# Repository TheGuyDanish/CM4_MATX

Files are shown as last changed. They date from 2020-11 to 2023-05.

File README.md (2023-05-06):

# CM4 MATX

## This project has been archived.

Due to a few different reasons, I have decided to archive this project. There's a few different reasons, but mainly that I don't think the CM4 is an appropriate platform for this kind of board. The CPU doesn't really have enough power to utilize the kind of IO that this board would provide it with, combined with the different limitations of using PCI-e switches. This, combined with the fact that I don't have as much time as I'd like to spend on this project, I've decided to leave it be for now.

I'm not aware at the time of writing of any similar projects, but I'll be leaving this one up for folks to take resources and inspiration from.

The original readme is below for archival purposes. So long, thanks for all the fish, and may you have the best of luck in your projects!

/TheGuyDanish

<hr />

Welcome! CM4 MATX is a project aiming to create an open source, micro-ATX standard-compliant motherboard for the Raspberry Pi Compute Module 4.

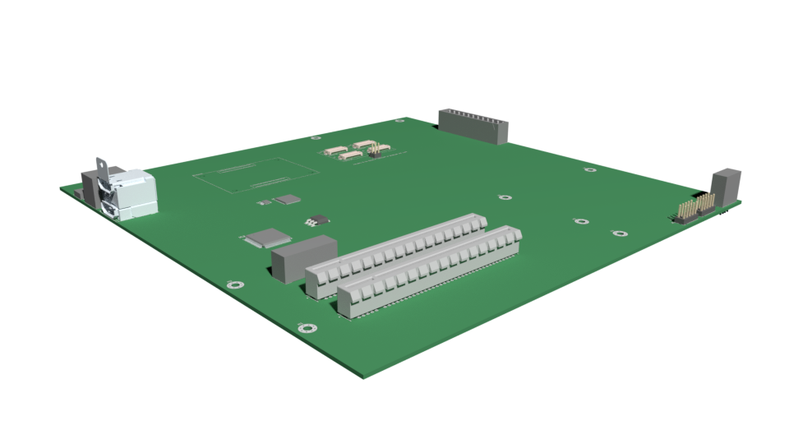
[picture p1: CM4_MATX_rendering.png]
3D rendering of the PCB (design not final)


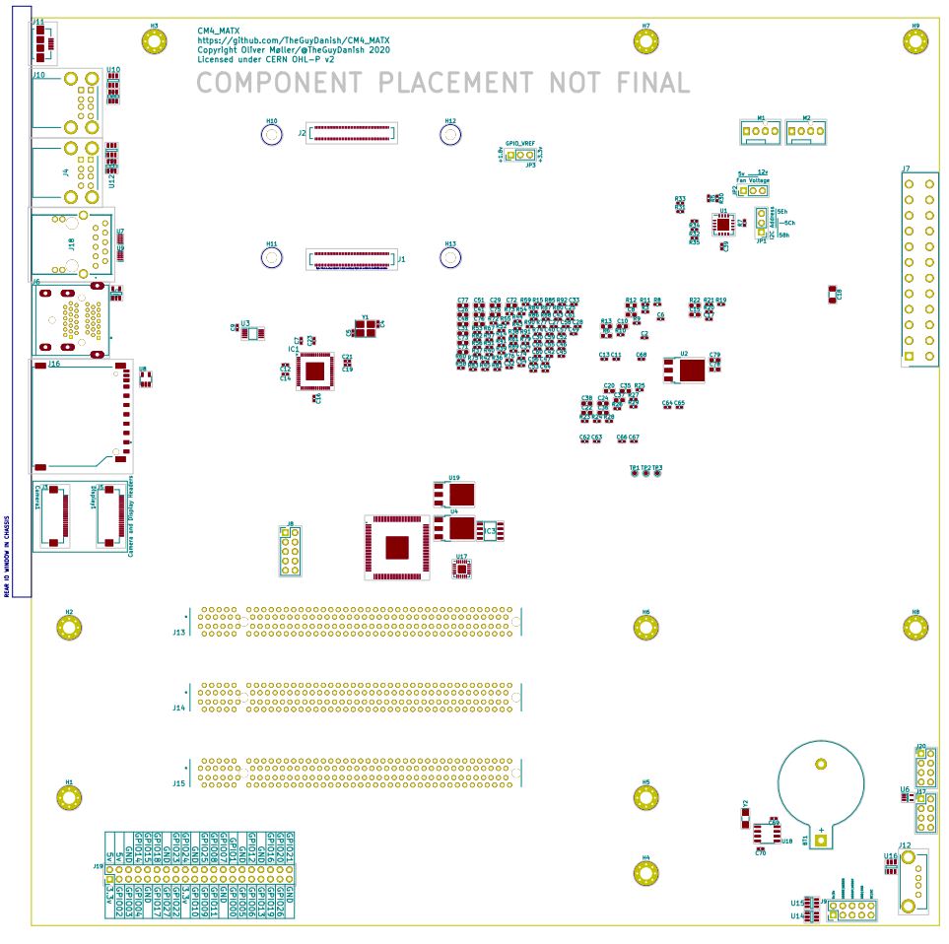
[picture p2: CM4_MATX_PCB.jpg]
PCB layout - click to view current PDF
<p align="center"></p>

The intent behind this is to provide a motherboard that can be installed in a regular case, as well as provide more, or easier access to, potential IO, as well as using a standard 24-pin ATX power supply. This project uses much of the CM4 IO board as its reference design, with new features added onto the board.

The current design goals are as follows:
* Use a standard mATX form factor (244*244mm) and mounting holes
* Provide dual rear-panel USB ports via USB2514B/M2 USB Hub
* Provide an internal USB expansion header for front-panel USB ports
* Provide a standard gigabit Ethernet interface for the rear panel
* Provide stacked dual HDMI outputs on the rear panel
* Provide stacked dual HDMI inputs on the rear panel, with the aid of the Toshiba TC358743 CSI2-to-HDMI bridge IC
* Where reasonably possible, expose the dual DSI headers
* Provide rear-panel acess to other RPI staples, such as SD card and 40-pin GPIO headers
* Via the PI7C9X2G404SL PCI-e switch IC, provide three lanes of PCI-e Gen 2.0 to host multiple expansion cards. These will be x16 slots, wired x1 electrically, to reduce the need for adapters
* Via the PI3PCIE2215 PCI-e mux IC, offer the user the choice between a physical PCI-e slot, or an NVMe slot using one of the downstream PCI-e lanes from the above switch.

# Help Wanted

Update: We have reached a state where we feel comfortable beginning to route the different features of the board. If you have experience with routing PCBs, you are very welcome to download the Kicad files and have a look for yourself. If you have any questions, feel free to join us on Discord if you have any questions and would like to reach out to me directly!

I (TheGuyDanish) am not an experienced board designer, nor a whiz at electronic schematics. That's why I am posting this to Github. I'd love for other hobbyists to join this project. Not just to correct my inevitable mistakes, but also to suggest new features that would make this board even better.

For technical specifics, the KiCad project was made in version 5.1.8 stable. All components not found in the standard KiCad library are included in the CM4_MATX.pretty folder (PCB footprints) and CM4_MATX.lib (schematic symbols) file.

Please see CONTRIBUTING.md for more information!

If you have the technical skills to improve this schematic, I do implore you to make a copy of the repository, make your changes and submit them in a pull request.

If you have ideas you would like to add to the design goals, please submit them in an issue so they can be discussed.

Lastly, huge thanks to volkertb, UnKnoWn-Consortium, mo-g and geerlingguy for the discussion of this in https://github.com/geerlingguy/raspberry-pi-pcie-devices/issues/19 that spawned this effort.

# License

NOTE: Some models, schematics, and/or footprints, are provided by individual manufacturers. As such, all terms and conditions for use, as well as licensing, falls to these original manufacturers. For more information, please inquire with the original component manufacturer or raise an issue here.

Copyright Oliver Møller/[@TheGuyDanish](https://github.com/TheGuyDanish) 2020.

This source describes Open Hardware and is licensed under the CERN-OHL-P v2

You may redistribute and modify this documentation and make products
using it under the terms of the CERN-OHL-P v2 (https:/cern.ch/cern-ohl).
This documentation is distributed WITHOUT ANY EXPRESS OR IMPLIED
WARRANTY, INCLUDING OF MERCHANTABILITY, SATISFACTORY QUALITY
AND FITNESS FOR A PARTICULAR PURPOSE. Please see the CERN-OHL-P v2
for applicable conditions

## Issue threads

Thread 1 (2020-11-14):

Pi-Standard 40-pin connector should be discarded

mo-g, 2020-11-14:
So in order to provide the high res 4-lane CSI, the i2c pins are needed. The i2s interface is also needed for sound capture from HDMI. By counterpoint, the CM4 exposes ADC interfaces on the SOM connector that are not exposed through the standard pi 40 pin. It also doesn't expose the 12V rail we have access to through the ATX PSU.

Additionally, the 40-pin IDC connector is not "external grade" hardware.

Since many hats already won't work with the hardware above missing, I propose making a "different" 40-pin connector exposed internally which is not pin-compatible with the standard Pi header, then breaking that out onto the I/O shield with a 37 pin D-Sub connector on a ribbon cable. - Inspired by the Be Inc Geekport.

TheGuyDanish, 2020-11-14:
A good point. This is easy to change this early (because I haven't drawn the 40-pin header into the schematics yet). Next prominent question is what other pins we might want to cut away if we are to put the GPIO on an alternate connector? I'm still leaning more towards exposing the GPIO as an IDC header on the rear-panel to keep it user friendly to anyone who wants to experiment with the GPIO. Rather than someone having to break out whatever connector we'd use instead back into regular 2.54mm pins.

mo-g, 2020-11-14:
By my count, 8 of the pins on the Pi header are Grounds. We could *probably* tie some of them together (says the non-electrical engineer)

Exposing it internally but offering a plug-in breakout gives people flexibility. They can use it entirely internally, for something like a panel-mount LCD or Fan control, or they can expose it through a safe and protected connector which has things like a screwlock to hold it in place, *or* they can just run a good old fashioned IDE cable out of any crack in the case to run it externally without having to solder up a DB37.

If we expose it only externally as IDC - they need to run a ribbon back into the case to do internal projects (fragile and inelegant) - and if using it on their desk, they risk knocking the cable out - potentially damaging their project or piatx logic, but almost certainly damaging the IDC header itself. I do NOT miss bending pins in IDE sockets trying to get a tight fitting drive cable out.

volkertb, 2020-11-14:
You two are obviously more well-versed in this than I am, but what about the way how the Raspberry Pi 400 has exposed these pins on the back? Would it make any sense for us to maintain some compatibility with that?

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

mo-g, 2020-11-14:
That's basically what @TheGuyDanish is proposing. The two reasons I'm arguing against that approach:

1. We can't be pin compatible anyway, and doings something that "looks" like a Pi standard is likely to lead to people breaking things by plugging "Pi standard" things into it.

2. A fragile connector like that is fine on the Pi 400 because:

- It's a cheap, £70 computer. The board we're designing would likely be more expensive.
- It's designed to be used on your desk or table right in front of you. An ATX case isn't - this connector is going to be awkwardly hidden away from you, and ribbon cables are a poor choice for that scenario - which is why desktop PC's always use D-sub connectors for UART, GPIO and A2D - because they are rugged connectors.
- And finally, as I said above, doing it this way prevents you from building something that sits internal to the computer - like an LCD or an ISA bus or a fan controller. That's fine on the Pi 400 because there's no free space inside it anyway and you can't easily open it to find out. Not true of an ATX case.

TheGuyDanish, 2020-11-14:
> (says the non-electrical engineer)

That's still more engineer than I am.

Entertain this thought for a moment. With the microATX standard, we can expect any case this board is put into to have room for four expansion cards. Given the PI7C switch IC we're using can only support three lanes, If we expose the IDC header (or whatever connector we end up using) at the bottom of the board, where the last PCI-e slot would be. It could be possible for a user to (somewhat elegantly, with a custom PCI-e bracket with the right cutout) expose the IDC header, should they really want to. Otherwise, it would be kept internal and can either be accessed or ignored, depending on the user preference.

mo-g, 2020-11-14:
That's basically the same concept as mine, except using a backplane slot rather than a D-Sub. I'm fine with that - reminds me of the way old Winmodems connected to boards in the late 90's, and allows people to export it as D-Sub, IDC, whatever they want - or mount it as an internal card, kind of like a custom "PiBus". I like that approach. Will need careful positioning to allow a simple PC case to have a standard ATX case bracket on and still align correctly with the IDC connector.

volkertb, 2020-11-14:
I like this Winmodem/"PiBus" approach too, the more I think about it. Let the community develop all sorts of interesting cards around this new form factor. Legacy I/O (serial, parallel), sound cards, cards that would expose the pins on the backplate in the form of the aforementioned Geekport or the same port as on the Raspberry Pi 400 if they want, etc.

Are there any kinds of I/O that we would still want to integrate on the board, and which would take up any of the GPIO pins? I believe one of you mentioned an on-board RTC, for instance?

TheGuyDanish, 2020-11-14:
On-board RTC is present in the CM4IO board and could easily be lifted if we want to integrate it.
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

mo-g, 2020-11-14:
I'd definitely be in favour of RTC, since it is pretty mandatory for any kind of server needing certificates. I've also already mentioned using i2c and i2s so that which can turn the pair of CSI2 ports into something useful. And I've mentioned a few times I want to ADD the A2D pins to the header, which are missing on the standard pi header. That said, I've just stuck a question up on the Pi forum because I'm a little confused about how i2c plays out with the CSI, etc.

I want GLOBAL_EN, RUN_PG (reset), LED_PWR, LED_nACT (HDD) on the fpanel connector but I don't think any are on the 40-pin header to start with.

TheGuyDanish, 2020-11-15:
@mo-g I've done some research this evening, and I actually think we can present i2c pins on the GPIO header without drawbacks. While the TC358743XBG internal registers _can_ be modified over i2c, it doesn't seem to be a hard requirement. If you look to some of the boards that demo it, such as the [Auvidea B101](https://auvidea.eu/images/auvidea/products/bridge/B101/B101_test_setup_RPi_600x350.jpg), they aren't connected to the GPIO pins at all, meaning the chip surely doesn't require the i2c connection.

In addition, after some more reading up, connecting two of these chips (which would be necessary to facilitate two HDMI inputs) to i2c would cause another conflict, in that they'd likely conflict on their i2c addresses. Newer versions of this IC have a specific selector to allow you to chose either a master or a slave i2c address to prevent these collisions, but the one we're looking at for this doesn't.

In summary: **_i2c for the people!_**
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
TheGuyDanish, 2020-12-12:
As I've had no comments on this, and the 40-pin header is now exposed on the port (location pending final placement), I'll go ahead and close this issue for now. Any outstanding comments are still welcome.

funkyguy4000, 2020-12-18:
Are we sure that we want the 40-pin header at the bottom of the board? It looks like there might be some overhang which might not allow the motherboard to fit in a standard Micro-ATX case if the user wants to use the 40-pin as is. It seems like we might have better luck having the spot where the 40-pin header is be some sort of other card edge connector, maybe a little offset a little closer to the bottom of the board, and then there would just be an adapter card that turned it into a standard 40-pin. That could then put the connector opposite the other side of the pi HAT so the traditional output side of the HAT is out the back like a standard PCIe card.

TheGuyDanish, 2020-12-18:
I'm anticipating that we may have more spare room on the bottom of the board, especially behind where the 40-pin header is located now.

We could move the 40-pin header further back, perhaps behind where the PCI-e slots are now, then let users decide if they want to put a HAT on it, or use something like a 40-pin IDC header to bring it somewhere else.

One of the ideas I think we originally discussed for this was something like a simple PCI-e bracket/card to expose the 40-pin header externally, so it would be similar to the Pi 400 in appearance. That way, people can use it, both inside the case, and on the outside, if desired. Though the placement of the header itself doesn't really matter in that context.

As ever, I'm happy to hear other options, though. I really want to avoid adding another layer of complexity to it in the form of new connectors. If any new connector is to be added, I would like for it to be one that is fairly common, that people wouldn't struggle to track down cables and mating parts for.

mo-g, 2020-12-21:
I previously had the same thought, @funkyguy4000 - but - if the 40-pin connector is aligned properly, a card with a female header block soldered to it and a standard PCIe bracket screwed on - would sit on the header no differently to using a card-edge.

If someone wants to use the hat connector, they could use a bigger case - or more likely, use a "vertical riser" that lets any ports on the hat stick out of the back of the case. That could also add a geekport connector, or a 40 pin HAT-on-the-Back, or something completely custom.

@TheGuyDanish
> If anyone has requests for other pins, please post a comment in here with their names and locations and I'll look into including them on a separate header near to the GPIO header.

`IP0, IP1. nRPI_BOOT, EEPROM_nWP` would be the other pins I'd want exposed on that connector.

If you went for a 48 pin header, then you could have IP0/IP1 as a row, pair each of BOOT/nWP with a ground to allow them to be pulled low, then have a pinless-row to keep them physically separate from the rest of the 40 pin?

TheGuyDanish, 2020-12-21:
@mo-g IP0 and IP1 will need to be exposed somewhere, for sure.

nRPIBOOT and EEPROM_nWP are already exposed on J20, the 2x4 pin header on the bottom right hand side of the board.

funkyguy4000, 2020-12-21:
Just throwing an idea out here, since the nRPIBOOT and EEPROM_nWP are critical to using the CM4, relative to the board purchased, would it be possible to wire those to toggle switches somewhere? Maybe the IO Shield, maybe somewhere internal? It'd be a simple feature to implement and a large portion of the users will need to do this function already.

mo-g, 2020-12-22:
Simplest answer would just be to have them on a header adjacant to a ground pin - that way they can be jumpered where they are, or put on a toggle with nothing more than a crimped plug and two lengths of wire. That gives a lot more flexibility as well, since you can run the wire to the back of the case, or to a front drive bay.

I don't see an I/O shield toggle being useful. For the effort of getting to it where my desktop is, I'm as well off to take the side panel off and change a header. I appreciate everyone's desk is different! I'd also be worried about accidentally switching it while moving the PC into place. Since you only need these for a firmware update (and most users of this aren't going to need to set nWP) or if you spectacularly hose your OS (BOOT) - I don't see them really needing easy external access.

Maybe an I/O shield DIP switch would work better, if you were to move them anywhere?

erkinalp, 2021-05-13:
With a +VCCs and a few GNDs merged amongst each other, a 29-pin HDMI dual link connector could be reused.

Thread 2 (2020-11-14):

Expose both a USB pin header and a USB-A socket internally

mo-g, 2020-11-14:
This is something cribbed straight out of Supermicro's playbook, but I think we should absolutely borrow it.

The design as current exposes two USB 2.0 headers. I propose we only expose one header and expose the other as a USB type A socket.

The reason is, there are many USB devices that would make sense to use internally in a Pi based PC which are only available with A connectors and not header blocks:

1. USB-SATA adapters. Many people use these, as they connect a standard 2.5" ssd to a USB socket. With an internal USB port, one could be mounted in a normal drive cage and still used as a Pi's boot drive - handy, since NVMe boot support is not available.

2. USB flash drive. See above, except cheaper. A USB flash drive could hold the pi's bootloader only, for booting to NVMe. Allows easy use of NVMe with the Pi CM4 lite, potentially allowing the eMMC interface to be used for something more useful. (We're exposing that as a header block too, right?)

3. USB-Floppy disk drive interface. Something like this - https://www.ebay.co.uk/itm/264239344659 - Which allows an internal 3.5" drive to be mounted for retrogaming fun. But, it needs a USB-A, not a header.

As an alternative to this proposal, I'd also accept headers-only, as long as they were two physically separate four-pin headers, and not the common two-port 9-pin header block. That would allow something like a single port version of this to be made to allow both internal or external type connectors to be used in any combination: https://www.ebay.co.uk/itm/383805792699

mo-g, 2020-11-14:
Another alternative - use USB2517 instead of 2514 - two external ports, two complete 9 pin headers AND an internal USB-A.

TheGuyDanish, 2020-11-14:
There's definitely a potential for this and I was considering it when I was writing the design goals in the README. Most internal USB headers will expect the two-row header that normally is used for exposing USB 2 ports.

Using the 2517 could be an interesting fix, seeing as it should be a more or less drop-in replacement. I'll look into that.

TheGuyDanish, 2020-11-15:
I didn't mention this when I committed it yesterday, but https://github.com/TheGuyDanish/CM4_MATX/commit/08fd37ccbf002c83fe7bd2444757735594c0ec7e put a lot of my work on this into the repo. The USB2517 is placed, as are two 2.54mm expansion headers, the dual-stacked rear-panel USB connectors, and finally the vertical USB A header on the board itself. Totaling to all 7 ports. The file https://github.com/TheGuyDanish/CM4_MATX/blob/master/CM4_MATX_PCB.pdf shows where I expect to put these on the board, but would love to hear other thoughts.

There is still some work to go for USB, though. Namely:
* The VBUS rail doesn't exist yet. On the CM4IO board, the VBUS rail is made by putting 5V through an AP22653W6 power switch IC and using the output (with one decoupling capacitor per port) as VBUS.
* Power still needs to be attached to the USB2517 chip. I haven't done an exact count as of yet, but it's likely we'll need a few more decoupling capacitors for 3.3v rail on the power inputs on the USB2517 (IC1) and the FSUSB42MUX (U1).

I plan to look into this on Tuesday.

TheGuyDanish, 2020-11-24:
I believe this has large been completed. Anything that might remain now are overall steps, not anything specific to this issue, closing.

Closed 2020-11-24.

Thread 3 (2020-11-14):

Integrate an IEEE 1284 (Centronics) parallel port (not through a USB adapter)

volkertb, 2020-11-14:
Although it's considered a legacy interface, I'd very much like to see a parallel port on the backplate of this motherboard, for various (retro) tinkering purposes. One that supports bit-banging, a low-level feature that USB to parallel port adapters don't offer.

Perhaps you could implement this fairly easily by integrating the pi-parport HAT design at https://github.com/worlickwerx/pi-parport into your motherboard design?

I'm not sure if this would take up any pins that are already required to offer other types of integrated I/O that you plan to implement, but if not, this would be really nice to have.

mo-g, 2020-11-14:
This would use up a bunch of GPIO (actually, nearly all of it) - BUT, this is exactly the kind of thing that could be done via the 40-pin connector if we mount it next to a backplane slot. You could expose a 40-pin IDC externally, my "geekport" or use this schematic plus a MAX232 to give a parallel port and a serial port as an expansion card.

This could also be used, if you wanted to keep the 40-pin connector for something else, as well:
https://www.dell.com/en-uk/work/shop/dell-parallel-serial-port-pcie-card-full-height-for-mt/apd/540-bcgv/networking

mo-g, 2020-11-14:
As a side note, I want one of these GPIO to Parallel+Serial Port cards if this board ever gets built! I can think of a lot of uses for that! :D

volkertb, 2020-11-14:
Interesting alternative suggestion. I wouldn't want to sacrifice a precious PCIe slot for it, though. Indeed, having some kind of expansion card that plugs in to the GPIO pins and exposes such ports on the backplane would indeed be the way to go.

By the way, I was about to open a separate topic for requesting an integrated RS-232 DE-9 port as well, but I guess that's part of the same conversation. (Except that an RS-232 port wouldn't require a lot of GPIO pins and therefore could perhaps be integrated after all. What do you think?)

TheGuyDanish, 2020-11-14:
There wouldn't be any sacrifice. As mentioned in #1, the switch chip only supports three downstream PCI-e lanes. Seeing as the mATX spec covers four, we can put an IDC header with the GPIO where the fourth slot _would have_ been. This would allow anyone to potentially install HAT-based expansions into that fourth slot. It would require a custom bracket/cutout to expose it externally. But there wouldn't be any sacrifice involved.

volkertb, 2020-11-14:
Yeah, you both have convinced me that that's the way to go. In that case, I guess I can close this thread, right? Since exposing the GPIO pins through an IDC header would be more flexible than hard-wiring an integrated parallel port to some of the GPIO pins.

TheGuyDanish, 2020-11-14:
I think it's safe to close this, yeah. While the idea behind this is solid. It does definitely lean more towards being one part of a greater "expansion card"/PiBus project.

mo-g, 2020-11-14:
Side note - my original thought process for this (@TheGuyDanish) might have a different perspective) is to try and expose as many of the features as possible. The reason I want us to use the i2c and i2s for the HDMI in, is because doing so allows us to make use of the otherwise useless CSI ports.

Making a DB9 serial port would remove the UART fro being able to be used internally, but like the Parallel port - you need little more than a single IC (MAX232 TTL-RS232 converter) which is a long since common chip for DIY projects. :) You could easily fit them both on an expansion card - and even have a flying lead out to a DB15 game port on the card, too. For that full 1993 experience!

TheGuyDanish, 2020-11-15:
Closing this for now as it's pretty much agreed that this is out of scope for the board itself.

(And also so we can close our first issue. 🎉)

Closed 2020-11-15.

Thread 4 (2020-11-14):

Expose SDIO as a header next to the I/O shield, not as a soldered SD Card slot

mo-g, 2020-11-14:
According to the launch blog for the CM4, by holding the SOC in a reset state, the SDIO interface can be used to access the eMMC on a full fat CM4 for programming. Outside of that case it can also be used to add an eMMC module to a CM4 Lite, as an SD I/O interface in the classic sense for external hardware (GPS, modems, etc), or.. as an SD card socket.

The CM4 Carrier hard limits all of that to JUST being used as a storage medium by using a uSD socket. We should expose it as pins, and allow the end user to attach an eMMC module, a full size OR micro SD slot via a simple passive shim, or use the SDIO functionality for another device - OR, connect it to another computer to access the eMMC.

TheGuyDanish, 2020-11-22:
I do think this is a good idea, but part of me is wondering how we could do this in an elegant way. I think for Rev.1, having a soldered SD Card slot is acceptable, mostly so we can also accommodate the CM4Lite boards that don't have on-board EMMC, but I would be willing to look into how we could work something like this out in a future revision.

Looking up examples like the ones you mentioned, GPS, modems, I see they use a full-size SD form factor. Would soldering on a full-size SD card socket make this more achievable? Given how almost every microSD card sold these days still comes with an adapter, I think it would be a reasonable option.

In a future revision (or if we have some time to implement it) something like a Fairchild/ONSemi [FSSD06-D](https://www.onsemi.com/pub/Collateral/FSSD06-D.pdf) could be an interesting option to allow either a microSD slot, or a second slot, perhaps via exposed pin headers to give the end user control.

mo-g, 2020-11-22:
Going for a full size SD card slot makes sense *anyway*. Given the issues SD cards have as long term storage devices - well, uSD and SD have largely the same capacities, speeds and price points... but uSD has a dramatically shorter lifespans. Full size SD is a much more sensible approach than micro.

I was basically picturing a header block, and a passive adapter that just wires the pins to a SD slot (probably with a right angle connector, so it sits horizontally when in a vertical case). But I think a full size SD is a decent compromise. If someone wants a bigger flash storage - NVMe is a better bet than a custom eMMC board anyway.

mo-g, 2020-11-22:
For SDIO devices - there are two types; the old PDA accessories, which were full size SD cards, and embedded devices like the Wifi interface on the CM4 itself. AFAIK these are electrically identical.

TheGuyDanish, 2020-11-22:
Just looked up a SDIO WiFi adapter and yeah, it does seem pretty similar.

In any case, I'll get on finding a decent full-size SD card holder to solder onto the board and put it on tomorrow.

mo-g, 2020-11-22:
I look forward to my first issue being closed. ;)

TheGuyDanish, 2020-11-24:
Full size SD card slot added in 9a986fd, resolving this.

Closed 2020-11-24.

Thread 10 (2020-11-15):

Can I take your licence and registration, please?

mo-g, 2020-11-15:
I'm kind of in favour of copyleft, since nice to get bug fixes from any company who makes money off this - but permissive is more likely to encourage somebody to actually make it.

Copyright assignment, or collaborative licence model? Contributors.md?

Or do you just want to CC0 (Public Domain) this?

But you should probably add a licence, anyway. :)

TheGuyDanish, 2020-11-15:
I think this should be up for some discussion. In software, I'm very much a fan of the MIT license and think it would suit this project well. (Make the changes you please, use it commercially, privately, whatever, just make sure you leave a footnote to us). I'm curious to hear what others think would be a good license to put it under.

As an aside, I'm also completely up for a CONTRIBUTORS.md, which I'm adding to my TODO list.

mo-g, 2020-11-16:
I also default to the MIT licence most of the time, or LGPL if I think it's something significantly worthwhile and complex that justifies forcing return contribution. This... while it represents a lot of work on your part, nothing in it is going to be spectacularly difficult to replicate.

I think we'd need to tweak the MIT licence as well - for one, every other word is software - we need to replace that with "hardware design, and hardware derived from it".

Also, as unlike software _patents_ are an issue for hardware designs, we should look to have some kind of "if you use, adapt or contribute to this design, you can't sue us for any infringement it makes on your patents" in the manner of MiniDisplayPort. Otherwise, we're asking for someone to make a contribution, patent it, then sue us for infringement.

We also need to be a *little* careful about borrowing designs from the IO Board Schematics. So far, both cases we've wanted to do that we've since done something completely different (USB, fan controller) but - you're probably best looking at the original IC datasheet for a reference design of the RTC IC rather than the I/O board datasheet, just in case the RPF decide we've infringed _their_ IP.

TheGuyDanish, 2020-11-16:
Regarding licensing, there is a specific "Open Source Hardware License". https://www.oshwa.org/definition/ It's a bit too late for me to read license text, but it could be a potential option.

And I do agree on the on the point of IP and _borrowing_. Reference designs will always be better than lifting it from other projects. In this instance, it is mostly done with the idea of rapid prototyping in mind, but there's definitely a concern there.

volkertb, 2020-11-16:
> Also, as unlike software _patents_ are an issue for hardware designs, we should look to have some kind of "if you use, adapt or contribute to this design, you can't sue us for any infringement it makes on your patents" in the manner of MiniDisplayPort. Otherwise, we're asking for someone to make a contribution, patent it, then sue us for infringement.

That's exactly why the [Apache 2 license](https://www.apache.org/licenses/LICENSE-2.0) is my favorite open source license: it has a patent retaliation clause. Other than that, it provides a high level of freedom in what others are allowed to do with the sources. Of course I'm no legal expert, and I'm not sure how well a software-specific license such as the Apache 2 license would apply to hardware designs.

Perhaps there is an open source hardware license out there that also has a patent retaliation clause?

garlick, 2020-11-16:
I've used CERN OHL 1.2 for some of my hardware projects FWIW, and it says something about patents:

https://ohwr.org/project/cernohl/wikis/FAQ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

(since this is my first time speaking up here, I also wanted to say "cool project!" :-)

funkyguy4000, 2020-12-09:
I would love to contribute to this project although I think the best avenue here is a permissive license like MIT or BSD.

TheGuyDanish, 2020-12-09:
Cheers, Shannon. Always happy to have more people on board! (pun not intended)

I'll be going over this on the weekend again and comparing options. So far, I'm leaning towards the CERN OHL, with a weakly reciprocal model (OHL-W). If my understanding of the OHL is correct, weakly reciprocal would mean that any changes made to the base design, schematics, etc, would need to be published. But any other additions (say new ICs on the board, for example for SATA or something along those lines) would not. I feel that's a fair distinction.

We could also apply OHL-P, which, hugely simplifying all the license texts, would be the BSD-equivalent of the hardware world. Anyone can take it, relicense, and use it without needing to distribute sources. In reality, I'm also fine with this option, but would like to see improvements directed back to the original repo.

The only hard stance I have at the moment is that I won't choose OHL-S, as I'm not really big into the idea of forcing anyone using parts of this in their own projects to publish _all_ of their design.

The relevant summary can be found in [the OHL wiki.](https://ohwr.org/project/cernohl/wikis/faq#q-what-are-all-these-suffixes)

funkyguy4000, 2020-12-12:
Sounds good! I wasn't aware those licenses exist. Personally I'm more of a permissive kind of guy.
(Also since I didn't introduce myself last time, hello! Really like this idea)

TheGuyDanish, 2020-12-14:
As of 371aa42, this project is now licensed under CERN OHL-P v2 allowing permissive use of all designs.

Closed 2020-12-14.

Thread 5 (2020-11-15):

Adding PoE Support

derwana, 2020-11-15:
YES i am perfectly aware of the ATX formfactor and the ATX-PSU coming with it. But i was thinking about all the other possibilities of powering a board: onboard MicroPSU or even only PoE.

I am currently diving into `IEEE 802.3bt` on PoE++ / 4PPoE which could give up to 70 effective Watt.

Nevertheless: i would really appreciate compatibility for a PoE HAT for not so power gussling usecases.

volkertb, 2020-11-15:
I'm not sure this project would fit your use case. The MicroATX form factor is intended to provide a desktop computing solution, which would be built in an ATX or MicroATX case, and include a PSU.

The point of PoE is that a compact device such as a WiFi router or perhaps some IoT device could be installed on a wall or ceiling somewhere, with a single wire providing both power and connectivity. I don't see the point in enabling something like that for a desktop PC case.

I do agree with you, however, that it would be very useful to have PoE support integrated in the regular Raspberry Pis, eliminating the necessity for a PoE HAT, and also offering a more reliable alternative method of powering a Pi than through 5V USB AC adapters, many of which are of questionable quality and often don't provide enough power for continuous stable operation.

mo-g, 2020-11-15:
Hmm..

I've actually thought about this as well. Most PoE modules are designed to output 12V. 12V at 35W, plus 5V at 15W would power this board, the SOM and a single 1 lane PCI-e card. So it's not unreasonable.  Something like an AG5800 module could potentially even drive a GPU and the SOM together. But, I think the additional cost and board space of building support for such a module is likely to be high for something that is specifically meant as an ATX board.

If you're using PoE for power, you're not realistically going to be using more than one PCIe card anyway - which means that a board like this would be wasted. But I'd be interested to see a poe+ enabled ITX "Routerboard" based on this but without the PCIe switch and a single x16 slot positioned for use with a passive single-slot riser in a 1U case. Would be neat as a drop-in for something like a Supermicro appliance.

TheGuyDanish, 2020-11-15:
I think this is a good option to keep in mind, but I don't think it's a "Revision 1" feature. I'm mostly concerned about people trying to use PoE to power the board, then getting upset when it randomly shuts off because there's not enough power. Assuming the user is educated enough about the limits, it could be an interesting prospect.

derwana, 2020-11-16:
> I think this is a good option to keep in mind, but I don't think it's a "Revision 1" feature.

@TheGuyDanish i am totally with you. Please add a handy label to this issue.

TheGuyDanish, 2020-12-28:
Closing this in favor of #47.

Closed 2020-12-28.

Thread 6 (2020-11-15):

Adding Fan Control Circuitry

derwana, 2020-11-15:
Seems overkill on first glance – but the CM4 might get very toasty on heavy loads. Maybe place a thermistor somewhere near the maximum heat spot under the CM4 to control that circuitry.

TheGuyDanish, 2020-11-15:
Fan control is definitely a good idea. Given that we have +12v from the ATX power supply, putting some [4-pin MOLEX fan headers](https://www.molex.com/molex/products/part-detail/pcb_headers/0470531000) on the board would be easy. If we can find a way to do PWM control from the Pi itself, we could even let the fan speed ramp according to CPU temp. Given that there's only two PWM pins on the Pi, I reckon something like the [MAX31790](https://datasheets.maximintegrated.com/en/ds/MAX31790.pdf) would be a reasonable addition. Six channels should definitely be enough to control all the fans a user would really need. But it does drive up cost.

derwana, 2020-11-15:
I am split in two. On the one hand i like the idea of reading the temperature and controlling the Fans via PWM for obvious reasons. On the other hand i am a simple guy: sticking a thermistor to the SOC and reading it with a [MAX6615 Dual-Channel Temperature Monitor and Fan-Speed Controller](https://www.maximintegrated.com/en/products/sensors/MAX6615.html). No PWM and additional programming required. Also it is [2.31$](https://www.maximintegrated.com/en/products/sensors/MAX6615.html/tb_tab3) (without the thermistor) compared to [2.70$](https://www.maximintegrated.com/en/products/interface/sensor-interface/MAX31790.html/tb_tab3) for the MAX31790.

TheGuyDanish, 2020-11-15:
I think the simplicity of the MAX6615 would be favored in this scenario. While the CM4 does get hot, I don't see an instance in which having 6 fans instead of 2 would make a remarkable difference. Setting a front and rear fan in one's case and a heatsink on the CM4 components should be good enough.

Do you want to have a stab at adding it to the schematic, or should I put it on my to-do?

derwana, 2020-11-15:
I am going to read the whole datasheet and will do a circuit for it – but may take some days. SMD or THM?

TheGuyDanish, 2020-11-15:
Not in particular. At this point in time, whatever you think is appropriate and decently priced is good. My plans for the (eventual) manufacturing of this board would be taking the board design and BOM to a vendor like PCBWay and getting quotes for getting the board printed and assembled. Either with us supplying parts, or them sourcing them. Which is also why I'm eager to keep costs down.

TheGuyDanish, 2020-11-15:
I'm hoping to take a break today and tomorrow from changing the schematics, so you've got a bit of time to run on. 😂

geerlingguy, 2020-11-15:
Note that the Pi IO Board itself just has an I2C PWM chip in line with the 4-pin fan connector. I haven't found a way to control it yet (mostly because I'm such a noob with I2C and there aren't any libraries for the chip they're using AFAICT). But that would be an option too: [CM4 fan controller lm-sensor](https://www.raspberrypi.org/forums/viewtopic.php?f=98&t=290795).

TheGuyDanish, 2020-11-15:
Good point, Jeff. The one built-in on the CM4IO is an SMSC EMC2301-1-ACZL-TR. The only downside of implementing it would be that it only supports a single fan. From what I can see, 2302, 2303, and 2305 exist as well, each supporting more fans (what the last model number symbolizes). All at decent prices. If we do decide to go down the i2c fan controller route later, an EMC2305 ([~€1.58](https://eu.mouser.com/ProductDetail/Microchip-Technology/EMC2305-1-AP-TR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) could be a good option.

TheGuyDanish, 2020-11-15:
Forgot to attach a screenshot, oops.
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

mo-g, 2020-11-15:
Stupid question - why would we need more than one fan?

A single fan will cool the SOM. Most uses of our HDMI-CSI and PCIe switch chips use no cooling, and an ATX case is going to have plenty of air for passive convection for those - plus anyone using SATA, SCSI, SAS or a GPU is going to be using a full PSU with a built in fan anyway, and overclockers.co.uk lists 36 different USB fan controllers that can be hooked up with our three internal USB ports. Given that the TDP of the BCM2711 is 7.5W, I don't see us making enough heat to need more even if this was in some kind of 1U case.

If the cost is negligible, a 2303 could make sense for front and rear case fans as well, but this seems pretty overkill. ;)

Says the person who worked out how to add a DisplayPort interface for triple monitors...

TheGuyDanish, 2020-11-15:
I do see your point, but consider how toasty the Pi4 got around release. 7.5W can still produce enough heat to thermal throttle it. I'm not sure if @geerlingguy touched on the temperature of the CM4 in any of his videos, but I imagine it _could_ be a potential throttling situation. In truth, we probably won't need fans. If a user wants to cool their CM4, chances are a passive heatsink would be enough to take care of the worst throttling. But at the same time, it's a small feature to add, and relatively inexpensive at that.

Unlike two Toshiba HDMI-CSI2 bridges. ;)

mo-g, 2020-11-15:
Point taken! Mouser said about 30¢ extra for the bigger IC, and we're not talking much more than that for the 4 pin connectors, so I'm in favour, I just don't know if we can actually *justify* a second or third fan connector on the basis of actual thermal needs. One is probably plenty - but YOLO.

If we can add an RGBI header, I'm also in favour of that.

geerlingguy, 2020-11-16:
Note that at the default clock, with natural convection and _no_ case, I did not see the Pi throttle (it stayed under 70°C the entire time I was testing it).

Overclocked to 2+ GHz, though, it would overheat after 30+ minutes of `stress-ng` if I didn't have some sort of air flowing over the chip. Adding a good heat sink would probably be adequate for passive cooling (assuming the case allows enough airflow).

Note that many PSUs have built-in fans to cool themselves, and most cards like GPUs that require more power and generate more heat have their own built-in fans too.

So one fan, IMO, would be plenty—the only use case where I see more being nice is if someone is putting in a ton of beefy hot hard drives for a NAS, and they want one fan for the drives and another for the Pi.

derwana, 2020-11-16:
> So one fan, IMO, would be plenty—the only use case where I see more being nice is if someone is putting in a ton of beefy hot hard drives for a NAS, and they want one fan for the drives and another for the Pi.

I'd consider myself as one of those NAS guys, building one with leftover HDDs and SSDs. Currently i got one in a 1U case and i would be happy to have more than one fan header. Only one connector for the fans in the front and back is quite messy with all the splitters and extenders.

mo-g, 2020-11-16:
Didn't consider drive cooling, I'm sold.

derwana, 2020-11-21:
Over the last days i did some research on fan control ICs and came to the conclusion that [EMC2301](https://www.microchip.com/wwwproducts/en/EMC2301), [EMC2302](https://www.microchip.com/wwwproducts/en/EMC2302), [EMC2303](https://www.microchip.com/wwwproducts/en/EMC2303), [EMC2305](https://www.microchip.com/wwwproducts/en/EMC2305) got the best price performance ratio so far (the [EMC2301](https://www.microchip.com/wwwproducts/en/EMC2301) is also on the Pi IO board). They can control 1/2/3/5 fans with different PWMs and are addressable over I²C compatible SMBus. But as Jeff mentioned:
> [..] there aren't any libraries for the chip they're using AFAICT. But that would be an option too: [CM4 fan controller lm-sensor](https://www.raspberrypi.org/forums/viewtopic.php?f=98&t=290795)

On the other hand we got chips from Maxim like the [MAX31740](https://www.maximintegrated.com/en/products/interface/sensor-interface/MAX31740.html) or [MAX6615](https://www.maximintegrated.com/en/products/sensors/MAX6615.html) who use NTC thermistor inputs to adjust the PWM fan signal. The first on is completely based on a voltage divider with the thermistor, does not require any configuration over I²C or similar and got one PWM Out. The second is more feature rich with fan-fail-safe protection, programmable fan-control characteristics and two PWM Out.

When the project is fully rebased to a stable KiCad version i'll do a circuit for MAX31740, MAX6615 and EMC2302 each – so we get some variety to choose from.

TheGuyDanish, 2020-11-21:
I've been making a lot of changes and think we're about to be at a point where the rebased branch is more developed than the Nightly one. So expect rebase to be merged into master at some point tonight or tomorrow.

derwana, 2020-11-22:
the three circuits are done – do you want them as separate pull request or as one?

TheGuyDanish, 2020-11-22:
Separately would be nice, if it isn't too much of a hassle. We can keep discussion of them to this issue.

TheGuyDanish, 2020-11-22:
Looking over the different chips and their datasheets, I'll admit I'm more drawn to the MAX6615, with the EMC2302 a close second. Looking at pros and cons, I think the 6615 would be nice from a "set it and forget it" perspective. We don't _need_ to put it on the SMBus and we can let it act off of the thermistors. But that is also quite inflexible, whereas with the EMC2302, there would technically be better options towards finer control.

The EMC2302 does concern me with the lack of seemingly any mainline kernel driver support. It appears a patch was submitted, but denied, looking at the LKML.

I think the best of the bunch among these three would be the 6615, but at the same time, I'd be enthused to see a fully-featured controller like the 2302 on the board, but with mainline drivers and support in lm-sensors. Perhaps the [MAX6639](https://pdfserv.maximintegrated.com/en/ds/MAX6639.pdf).

Any thoughts on that?

(I managed to find a list of lm-sensors supported hardware monitoring chips [here](https://www.kernel.org/doc/html/latest/hwmon/index.html#hardware-monitoring-kernel-drivers) in case we want to do more digging on this. [See for example the MAX6639 page.](https://www.kernel.org/doc/html/latest/hwmon/max6639.html))

derwana, 2020-11-23:
Call me stupid - i missed out that list completely, although it is in my bookmarks. I'll revisit this later today.

TheGuyDanish, 2020-12-22:
@derwana Have you had any chance to look at this? I'm starting to look into the MAX6639 as a potential candidate but I'm trying to get a hold of one to do some testing with (Which might end up being in the new year). Just curious.

derwana, 2020-12-22:
Yes i have. One with MAX6651 is finished, but i am not satisfied with it at all. The MAX6639 and maybe MAX31790 are the next ones on my list.

TheGuyDanish, 2020-12-22:
Okay, cool. I think the 6639 is a good one to go for, considering the support it has and the seemingly simple layout. In that case, I won't look too much further into it right now. Cheers mate.

TheGuyDanish, 2020-12-23:
Closed by #36

Closed 2020-12-23.

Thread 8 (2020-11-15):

Consider a RTC solution that interfaces with USB, to save GPIO pins

volkertb, 2020-11-15:
Wouldn't it be better to integrate a USB-based RTC into the motherboard design, as opposed to a GPIO-based one, to save pins?

Something like this perhaps: https://easyeda.com/rodyne/USB_RTC-dfce249ec7af4d7380d69c51a7e2cfec

USB (at least theoretically) supports up to 127 concurrently connected devices. Therefore, whenever integrating any functionality on the motherboard that can be implemented over either USB or GPIO, USB should be the preferred way to go, right?

TheGuyDanish, 2020-11-15:
While I think the theory behind is good, some things are just not worthwhile to integrate over USB. While I'm sure USB-RTC is something that works, I think acquiring it would be more expensive than implementing the CM4IO way of doing RTC via a dedicated chip and battery.

The PCF85063AT IC that is used on the CM4IO board to provide RTC is $0.69 for a single chip. That, combined with the fact that it doesn't use up any GPIO pins (since i2c is a bus), makes it a poor candidate for replacement. I doubt one of these USB-RTC devices could beat $1-2 in price.

As it stands right now, my current plan is to wait for #6 to be completed, then get the PI7C PCI switch integrated properly. With 3 exposed PCI-e slots, the GPIO header, and 7 USB ports, we should have more than enough IO for any early-adopter of the CM4 to toy around with.

Once the items mentioned above are integrated (and I've hooked the USB hub up with power), we can place the PCI-e slots and GPIO header to get traced on the PCB. After that, we could get a first quote on what board assembly would run up to.

For any board assembly quote, I plan to open an issue and tag all active participants, highlighting the features, slots, pricing per board and the total price for the smallest feasible batch. We can then discuss if we'd like to make an order for that board revision or wait until we've had more time to work on it.

volkertb, 2020-11-15:
Ah, it works over i2c and  doesn't take up any GPIO pins? In that case, forget I mentioned this. Thanks. :sweat_smile:

Closed 2020-11-15.

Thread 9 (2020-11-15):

Perhaps use open-ended PCIe x1 slots instead of PCIe x16 slots?

volkertb, 2020-11-15:
Wouldn't it be preferable (and equally flexible) to use open-ended PCIe x1 slots instead of full-blown PCIe x16 slots that would be wired up as x1 slots?

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

It would make it clear that these are indeed just x1 interfaces, and there would also be a lot less solder points and PCB real estate required, so perhaps it would simplify the board design a bit as well?

The one challenge here might be that such slots could be difficult to source, at least judging from [this Reddit discussion](https://www.reddit.com/r/pcmods/comments/5xav00/purchasing_an_openended_pcie_connector/), although it's 3 years old, and availability may have improved since then.

TheGuyDanish, 2020-11-15:
Hmm. I'll look to see if I can find them anywhere. Until then, can someone figure out what Red Shirt Jeff's hourly rate is? 😂

volkertb, 2020-11-15:
I'm sorry, I didn't get that reference at all. :sweat_smile:

mo-g, 2020-11-15:
@volkertb It's a Jeff Geerling reference.

TheGuyDanish, 2020-11-15:
Red Shirt Jeff is Jeff Geerling's altar ego, to whom the Dremel is the answer to all problems.

volkertb, 2020-11-15:
Ah, okay. I didn't start following him on YouTube until recently. But a search for "Red Shirt Jeff" on Google didn't turn up his YouTube channel yet.

By the way, I tried to cut an opening on a regular close-ended PCIe x1 slot a while back. My hacky method was to heat up a small screwdriver with a soldering iron and then melt open a slit. I didn't have a dremel on hand. Unfortunately, I didn't do a good job at it, since it ended up not working. The right tool for the right job, I guess. :grimacing:

Honestly, I don't understand why not all motherboard manufacturers just use the open-ended variants of the x1 slots these days.

mo-g, 2020-11-15:
Two reasons why not:

First, it offers more physical support. So, if you've got a big heavy GPU in a tower case without a support at the far end of the card, a 1x slot means a lot of leverage on the slot and backplane. A 16x slot distributes the load better.

Second - a 1x slot and a 16x (1x electrical) slot are not electrically identical. While the 16x slot still only has the same signal conductors, it gets additional power and ground pins. Officially, a 1x slot can only offer 25W whereas a 16x (1x electrical) slot can offer 75w. This is why 1x to 16x risers have a Molex on them - to provide the additional power rails. Since we're expecting people to plug more than a 1x USB 3 card in here, we should really go for the full wattage slots. Otherwise people couldn't put (for example) a GT 1030 card in here - the open 1x slot wouldn't provide enough power and there's no-where to put a powered riser card in the ATX case.

TheGuyDanish, 2020-11-15:
Having looked through Mouser, Digi-Key, LCSC, as well as a few manufacturer pages. Open-ended x1 ports seem near-impossible to find. :/ That, along with the points @mo-g makes illustrates pretty well why x16 would still be a better choice, compatibility-wise.

geerlingguy, 2020-11-16:
I think the major thing I would want in either case is good labeling / silkscreening on the board—the IO board has a very nice "PCIe x1" label next to the slot that makes it immediately obvious it's a 1x port (besides the physical size).

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

I agree with @mo-g that a 16x slot is nice for the added support. Red Shirt Jeff has been doing some testing with different slots and found that it's annoyingly unstable to plug in heavier cards with big heat sinks/fans built into shorter slots, because they have a tendency to lean away from the slot as @mo-g mentioned.

mo-g, 2020-11-16:
Sensible. I'd *like* to think that anyone who knows enough to be looking at this would know they're 1x slots without a label. But unfortunately, I'm optimistic - not naive.

volkertb, 2020-11-16:
You've all made some good arguments against this. PCIe x16 slots it is! Closing this issue.

Closed 2020-11-16.

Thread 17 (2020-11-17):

Rebase the project to KiCad 5.1.8

TheGuyDanish, 2020-11-17:
As was seen in #15, the nightly builds of KiCad have some issues with save compatibility between operating systems. A great way to avoid this is to use stable versions of the software. (I'm gonna take the fall for that one.) And we should make an effort to move CM4_MATX towards using a stable version.

Given we already have a bit of a base to work from, it would be nice to be able to somehow export the current work into a format that will then be readable by stable, but I doubt that will be the case. I've started a local rebuild of the project and I'm currently gathering all the schematics and footprints required to get it going.

My first challenge is that the CM4IO board, from where the actual Compute Module 4 schematic and footprint was taken, uses KiCad Nightly as well. Meaning that the resources taken from there are incompatible with stable.

While these are issues that could be worked around, it would take some time to figure out.

I'm looking into this as a priority so we don't have people wasting time building schematics or designs that cannot be directly transferred to the project.

volkertb, 2020-11-17:
Are you sure this is worth the effort? To quote the README of the CMIO KiCAD sources:

> These files have been created in prerelease version 6 of KiCAD. If Version 6 isn't released yet then to use them you will need to download a nightly build of KiCAD. NB Nightly builds my have issues so please check the issue tracker.

That would imply that the Raspberry Pi developers purposely picked the nightlies, anticipating an upcoming KiCAD 6 release, and perhaps wanting to take advantage of the new features in that version.

Your project appears to be opening just fine with the nightly builds of KiCAD I've tried so far.

TheGuyDanish, 2020-11-17:
I'm not too sure at the moment. The current "due date" on their Gitlab for 6.0 Epics is December 31st. That's a lot of time to wait for a workable release, and I don't feel like it's reasonable to ask people to use a Linux version of KiCad because "it's the one that works with the project files". It's a workaround, but I don't think it's a viable one. Most of what's currently in the repository was put together by me over a weekend with reference to other works. I could do that again.

TheGuyDanish, 2020-11-19:
@derwana @ddkaiser @garlick (Sorry to tag you directly, gents)

After nine hours of work with very few breaks, I've made the first commit in the kicad-5.1.8-rebase branch (9a5b4a5).

Rather than trying to figure out a way to convert schematics, PCBs and symbols, I opted to do it the hard way, as I found the only symbol we really needed was the CM4 itself (annoyingly). But I have created a symbol for it and discovered a footprint made by @aep that looks very close, though I haven't made exact measurements. (His original post about it can be found here: https://github.com/raspberrypi/documentation/issues/1717). From there, I have drawn a lot of the schematic content from the old version, though more is still to go that I'll attack in the coming days. The PCB is currently back to square 1, but again, the only thing we had in there that is any kind of bugger to redo is the mounting hole placement.

In addition, this commit also includes a revised CONTRIBUTING.md in order to take us forward with #18.

My ask for you, whenever you have the time, would be to check out the branch, ideally in as many different KiCad installations as you can and ensure we have good compatibility and that I haven't missed anything when rebasing it. If it all looks good to you guys, we can merge it into master and work on that going forward.

I know some components and footprints are missing from the old CM4_MATX library used in Nightly. But I reckon some of them are better added once we actually put them down in the schematic, as well as having changed a couple of components here and there.

It's 1 AM now, so I'm gonna get some well deserved rest.

derwana, 2020-11-19:
Cheers mate! Great work!

Currently i am on version `5.1.7-a382d34a8~87~ubuntu20.04.1, release build`.

On loading the footprint editor the error  `Footprint library path "C:/SamacSys_PCB_Library/KiCad/SamacSys_Parts.pretty" does not exist` gets thrown – but can be solved by removing it from the Project Specific Libraries.

Otherwise there are no errors and missing items on my version you haven't mentioned already (some schematic content, mounting holes). I'm going to redo the latter in the next couple hours.

TheGuyDanish, 2020-11-19:
D'oh. I must have forgot that. Oh well, if you're pushing the PCB at some point, I can piggyback removing that library off of your commit. 😂

derwana, 2020-11-19:
can confirm it is working too on Ubuntu with version `5.1.6+dfsg1-1, release build`

garlick, 2020-11-19:
I'm running `kicad-5.1.8-202011012012+db9833491~87~ubuntu20.04.1` from the [kicad ppa](http://ppa.launchpad.net/kicad/kicad-5.1-releases/ubuntu).

No real problems browsing around, although, after annotating, I did get this error when I opened the "assign footprints" dialog in eeschema:

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

Maybe nothing to worry about but wanted to mention it.  If I agree to the conversion it looks like it just tacks on ` CM4_MATX:` to the front of project footprint refs in the `.sch` files?  Here's an example (ignore annotation related changes):
```diff
diff --git a/KiCad/CM4_USB2_HUB.sch b/KiCad/CM4_USB2_HUB.sch
index 7793ba4..f8bc519 100644
--- a/KiCad/CM4_USB2_HUB.sch
+++ b/KiCad/CM4_USB2_HUB.sch
@@ -14,12 +14,12 @@ Comment3 ""
 Comment4 ""
 $EndDescr
 $Comp
-L CM4_MATX:USB2517-JZX IC?
+L CM4_MATX:USB2517-JZX IC2
 U 1 1 602002E2
 P 1250 2600
-F 0 "IC?" H 4350 3100 50  0000 L CNN
+F 0 "IC2" H 4350 3100 50  0000 L CNN
 F 1 "USB2517-JZX" H 4350 3000 50  0000 L CNN
-F 2 "QFN50P900X900X100-65N-D" H 4300 3800 50  0001 L CNN
+F 2 "CM4_MATX:QFN50P900X900X100-65N-D" H 4300 3800 50  0001 L CNN
 F 3 "http://ww1.microchip.com/downloads/en/DeviceDoc/2517.pdf" H 4300 3700 50  0001 L CNN
 F 4 "USB 2.0 Hub Controller 7-Port QFN64 USB2517-JZX, USB Controller 7-channel 480Mbit/s USB 2.0, 3.3 V, 64-Pin, QFN" H 4300 3600 50  0001 L CNN "Description"
 F 5 "1" H 4300 3500 50  0001 L CNN "Height"
```

TheGuyDanish, 2020-11-19:
Yeah, that doesn't seem too concerning to me. I might go through them all on my next browse around the project and make sure that conversion has happened, just so no one is confused by it.

aep, 2020-11-19:
> But I have created a symbol for it and discovered a footprint made by @aep that looks very close

fwiw, i can verify it works https://twitter.com/arvidep/status/1329457736719994886/photo/1

TheGuyDanish, 2020-11-19:
@aep Thanks, and thank you as well for stopping by! It was on my todo list to shoot you an email to ask if you'd have any problems with me snatching that footprint for use in this project. Thank you for the work in recreating the footprint!

aep, 2020-11-19:
> with me snatching that footprint for use in this project

not at all. looking forward to your board. In fact i might steal back because i need ATX power supply later :D

Closed 2020-11-22.

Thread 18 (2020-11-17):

refine project workflow

garlick, 2020-11-17:
> Considered a best practice by [some](https://hackaday.com/2017/05/18/kicad-best-practises-library-management/).

I agree with Jim G here on the library best-practice.  I have been able to clone others' projects more successfully when they had the Project Library included with the project source.

When having multiple editors working in KiCad, with a shared workspace (i.e. Github), having a 'Project Library' for symbols & footprints is common.  This practice also places these parts under version control (Github) and they "live with the project" as time goes by, leading to easier recovery of old projects.

@TheGuyDanish perhaps you could make the library management conditions part of your CONTRIBUTING doc, i.e. one of these two workflows (or your own)?

Workflow Idea 1 (always use Project Library)
- when placing a symbol or referencing a footprint, only reference the CM4_MATX Project Libraries, and migrate components from standard libraries to the project within the working session.

Workflow Idea 2 (use standard libraries, and 'freeze' components to the project library on release):
- Standard symbols and footprints can come from standard libraries, but if adding a new custom part, it must be in CM4_MATX libraries.
- When moving to tag a release in Github (a major milestone on the project perhaps?) symbols and footprints are copied from the standard locations to the Project Library versions.  There may be some Python scripts to automate some of this, or perhaps the 'Edit Symbol Library Links' and 'Assign Footprints' menu options within eeschema (I've done search/replace copy/paste for these fields on a medium sized, 500 component, project.  It takes some time.)

You could (over time, and as you see fit to do so) add other best practices, for example:
- SCH files must pass ERC before sending in a pull request.  (or exception is noted in the pull request comments)
- PCB files must pass DRC before sending in a pull request.  (or exception is noted in the pull request comments)
- Files must be named as (whatever file-naming standard) i.e. CM4_\<component_name\>   (Looks as this has been done well so far)
- Subsheet files should be in the same directory as the .pro and toplevel .sch file.   (unless you want some contributors work coming in subdirectories...)
- etc.

These things become more important as you move past 4-5 contributors, so choose and implement at your discretion.

These type of practices are used often in distributed software development work, (except the software-team dev practices are: builds must be passing compilation with no errors before checking in a file, files have to follow naming standards, source code requires comments per function, etc.)

_Originally posted by @ddkaiser in https://github.com/TheGuyDanish/CM4_MATX/issues/15#issuecomment-729245879_

garlick, 2020-11-17:
Nicely stated.

I wanted to add that github workflows may be able to automate some of these checks on PR's, to the extent that they are scriptable.

TheGuyDanish, 2020-11-17:
https://github.com/marketplace/actions/kicad-exports It seems some people are already ahead of us on the automation front.

TheGuyDanish, 2020-12-28:
We've come quite a ways on this (implementing automated CI today, with the ability to enable DRC/ERC checks later when the board is in a better state to pass such tests), and I plan to write more contributing documentation soon.

I'll close this for now as we've made some good progress, and I have more TODOs lined up in line with it.

garlick, 2020-12-29:
Great work!

Closed 2020-12-28.

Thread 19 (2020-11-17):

CM4_MATX.kicad_pcb has hard-coded Windows-specific links to SamacSys 3dshapes

volkertb, 2020-11-17:
I noticed the following when I tried importing the KiCAD project in FreeCAD, using the KiCadStepUp addmon.

Apparently, in addition to the default library location in $KISYS3DMOD, this project has been configured to assume hard-coded locations of 3D images of some of the components in the default Windows installatoin folder of the SamacSys ibrary Loader.

If you type the following command:

```
cat CM4_MATX.kicad_pcb | grep -i samac
```
That results in this output:

```
    (model "C:\\SamacSys_PCB_Library\\KiCad\\SamacSys_Parts.3dshapes\\72309-8014BLF.stp"
    (model "C:\\SamacSys_PCB_Library\\KiCad\\SamacSys_Parts.3dshapes\\PI7C9X2G404SLBFDE.stp"
    (model "C:\\SamacSys_PCB_Library\\KiCad\\SamacSys_Parts.3dshapes\\USB2517-JZX.stp"
    (model "C:\\SamacSys_PCB_Library\\KiCad\\SamacSys_Parts.3dshapes\\39-28-1243.stp"
    (model "C:\\SamacSys_PCB_Library\\KiCad\\SamacSys_Parts.3dshapes\\SS-52100-002.stp"
    (model "C:\\SamacSys_PCB_Library\\KiCad\\SamacSys_Parts.3dshapes\\10104110-0001LF.stp"
    (model "C:\\SamacSys_PCB_Library\\KiCad\\SamacSys_Parts.3dshapes\\10018783-11200TLF.stp"
```

Obviously, this will only succeed in when you're running KiCAD in Windows, and even then only if the SamacSys ibrary was indeed installed in that folder.

Now ideally, we would want to include any 3dshapes that are not provided in the standard KiCAD llibrary, and refer to them through a closs-platform project-relative path. Unfortunately, there's the license of these 3D models to consider. The ones from SamacSys are apparently "free as in beer" (not sure what the exact terms are in the fine print), but that doesn't necessarily allow us to distribute them with these sources

For an optimal render that will look close to the actually envisioned end product, we need 3D models of the components that will go into the design.

Any ideas on how to tackle this?

TheGuyDanish, 2020-11-17:
This should be solvable with some more copying and pasting. I use SamacSys Library Loader for getting lots of models, schematics and footprints from Mouser. I just have to take note of this and remember to copy over the 3dshapes as well. For now, I think this depends a bit on #17, though.

TheGuyDanish, 2020-11-22:
Resolved by 8946d66.

Closed 2020-11-22.

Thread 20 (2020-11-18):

atx style power control

garlick, 2020-11-18:
Has there been any discussion about ATX style power control?  E.g. press the power button once and the OS shuts down, and then powers off.  Hold down the button to override the OS shutdown.

Here are a few references to some pi-related stuff that might be of use:

**soft power off**
This device tree overlay can be used to map a GPIO to key 116 (power key):
https://www.kernel.org/doc/Documentation/devicetree/bindings/input/gpio-keys.txt

pi specific discussion here:
https://www.raspberrypi.org/forums/viewtopic.php?f=107&t=115394

You can then use a custom udev rule to map this to "power-switch" tag.  Systemd then gets ahold of the event and can initiate the shutdown, and finally take the action configured in logind.conf according to its HandlePowerKey setting, which defaults to "poweroff".

**turning off ps**
After the OS has shut down, you want to signal to the ATX power supply that it can turn off.  Here's a discussion about a pi-specific overlay that maps a GPIO pin such that it changes state once the OS has halted the CPU:
https://www.raspberrypi.org/forums/viewtopic.php?t=201483

Lots of ways to implement this, but I'll stop there - maybe this has already been thought about?  (Apologies if I missed it!)

mo-g, 2020-11-20:
Yes. We're (by which I mean @TheGuyDanish ) is already working on that, but hardware hasn't arrived yet to see how the power enable and reset pins behave under different conditions. I'm hoping to get a kit next week, with luck.

mo-g, 2020-11-20:
Just to summarise - I don't think we're looking to add a "shutdown key" in the sense of the ACPI "if you press this key, the system will exec `shutdown -h now`"- but instead, something to power the pi on after you shutdown from cli or normal graphical interface.

Also Run_PG as a hardware reset for a Pi that's locked up.

garlick, 2020-11-20:
Oh thanks for that reference.  To be honest I didn't follow it all, but I'm at least glad you're all over it.  IMHO, would be nice if one got more or less the same power button semantics as you get with a PC's power button, for principle of least surprise and all that.  I'm still a bit unclear if that's the goal or if you have something else in mind.

TheGuyDanish, 2020-11-20:
@mo-g Showing your age, buddy. ;) Jokes aside, my case still has a dedicated reset switch, they're just usually much smaller in size than the power one. So keeping it around is still a good idea, imo.

And yes, as was mentioned, I've got a CM4 and and IO Board incoming Soon(TM), as soon as they're in stock at Pimoroni. Once I've got it, I'll be looking into how GLOBAL_EN and RUN_PG behave and how they might be used for controlling power to the system. I'm still quite happy to take ideas and look at schematics if anyone has them.

geerlingguy, 2020-11-20:
@TheGuyDanish - Note that for the power situation, there's also on the IO board, J2 pins 13-14, which in the description state:

> Connect a push button to wake up the CM4 from low power mode. It can’t be used to shutdown the CM4.

Basically, when I do a `shutdown`, if I want to boot the Pi back up, I can just put a jumper on those two pins, when I pull it off, the Pi powers up. So it's not on button down, but on button up when it triggers the boot.

I haven't touched the J1 pins yet (in fact, I didn't even know where they were until I noticed you mentioning them!). There are no pins installed on the IO board, so I'll have to solder some up to see if they work as expected (I often have a need to hard-reset the Pi, so it would be nice to have for convenience's sake!).

mo-g, 2020-11-20:
> @TheGuyDanish - Note that for the power situation, there's also on the IO board, J2 pins 13-14, which in the description state:
>
> > Connect a push button to wake up the CM4 from low power mode. It can’t be used to shutdown the CM4.

That's also linked to the GLOBAL_EN pin we've mentioned elsewhere, with a latch to RUN_PG to disable the pin when the system is powered up.

I hadn't actually realised this jumper existed, so when I described this exact concept in your issue, I was inventing it in parallel. :facepalm: I spent a lot of time thinking about how that would work, should have just read the IO board datasheet. :roll_eyes:

mo-g, 2020-11-20:
> @mo-g Showing your age, buddy. ;)

Aren't I just? I'm rapidly heading for my mid-thirties, it's scary...

mo-g, 2020-11-21:
> would be nice if one got more or less the same power button semantics as you get with a PC's power button, for principle of least surprise and all that. I'm still a bit unclear if that's the goal or if you have something else in mind.

Problem is - that's not something the Pi offers us. We can build a 1996-style ATX power button with nothing but a single logic gate - and the Pi IO board already does this. To build a 2003+ style ATX power button, we'd need to add our own logic - to count the amount of time the button is held down for, and send a shutdown key if the system is up; manually cut power if it's held down too long, power on if pressed while the system is off - $0.50 microcontroller and about 50 lines of C. No big deal - but as of right now, nothing on the board needs programming - solder, plug in CM4, go. Adding our own "Power Management Unit" would now mean IC's have to be programmed either before or after soldering, which is likely to be a much bigger cost than just the part itself.

I don't think we should rule it out; but we should be careful how much a force-off gesture is worth in terms of cost, as opposed to just pressing the reset button.

HaasJona, 2020-12-14:
It should be possible to build this simply in hardware without programming a microcontroller. Probably just needs a 555 or 556 timer ic and a few transistors or mosfets for the logic and cutting the power. The button could connect to the already present power-up gpio line, which could be polled by simple software to shut down the PI gracefully (if pressed shorter than 20 seconds).

TheGuyDanish, 2020-12-28:
I think to begin with, a more simple solution to go for, unless someone can contribute with a more involved schematic, would be to go for a simple PS_ON soft latch. If Global_EN is low, signalling the Pi is off, and the power button is pressed, latch PS_ON to GND. If Global_EN is high, signaling the Pi is on, and the power button is pressed, remove the latch, turning off the power supply again.

I discussed this with @funkyguy4000 on Discord (link in #29) and we agreed that while having full, ATX-style power supply control would be nice, managing the timers and power states in an electronic circuit isn't something we've had any solid idea for how to implement.

For now, I suggest we implement the latch circuit as mentioned above and use that moving towards revision 1. If, by the time we reach revision 1, someone has a more fully-fledged circuit to take care of the other concerns, I'd be happy to add it in. But in the spirit of getting this moving, I'm more willing to go with the other option.

TheGuyDanish, 2021-01-18:
Currently shopping for some components so I can test it out in a physical circuit, but I'm looking towards this as a potential option for the first board revision:
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

(Borrowed from here: http://www.mosaic-industries.com/embedded-systems/microcontroller-projects/electronic-circuits/push-button-switch-turn-on/latching-toggle-power-switch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)

volkertb, 2021-01-20:
Is this ATX soft power circuit design from the Commander X16 project useful for the CM4_MATX project in any way?

https://youtu.be/Y-c3c3ia9Bo?t=297

bluerise, 2022-01-02:
I think the STM6601CM2DDM6F could be a good solution. It's a power-on push button controller designed for that specific use case: https://www.st.com/content/ccc/resource/technical/document/datasheet/1f/9e/3b/43/ec/04/44/71/CD00226957.pdf/files/CD00226957.pdf/jcr:content/translations/en.CD002269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

This design is used on the HoneyComb LX2K mini-ITX board (also ARM), and I think it would make sense here as well: https://developer.solid-run.com/download/clearfog-cx-and-honeycomb-schematics/ -> mitx-cex7-1.3.pdf

It provides an interrupt pin for 'short push', so that the OS can power down safely. On long-push it also provides that and after some time disables EN. The chip is powered by standby 5V, and controls the power-supply ON pin on the ATX header. The PS_HOLD pin can be used by the processor to force power-off. Seems like a nice setup.

On Discord concern was raised about the comment "The push-button controller is configured in a way that powers-on when ATX power is available.", that this should be made configurable, e.g. through a jumper. I wonder how it's implemented. Maybe C1/C2 pull down the button long enough when power comes in initially. Maybe adding a jumper before those would help make that configurable?

myself248, 2022-01-02:
There's obviously a fair bit of complexity here, so for rev 0, I'd like to put all this on a daughterboard, and just have a simple "short /PSON" bypass jumper for when you don't want to bother with all that. Then we can make boards carrying an STM660x, rp2040, atmega, esp, 555, who knows what else, and hammer out the desired functionality.

(I initially suggested making this a standard footprint like micromod, and Danish suggested a Pi Pico footprint, but given that there are 5v and 12v signals in here, that's not so practical without support circuitry on the mobo, which kinda defeats the purpose. Maybe the signal conditioning wouldn't be onerous. Maybe a Pico-with-extension that the normal board wouldn't cover but a purposebuilt could....)

Anyway, planning into that, I'm making a list of all the signals that might possibly be needed now or in the future for advanced functions. To start:

- GND, beacuse if I don't write it down I will forget it...
- +5VSB from the ATX PSU
- +12VSB from the ATX12V PSU
- nPS_ON from the ATX/ATX12V PSU
- +5V from the ATX PSU
- +12V from that ATX/ATX12V PSU
- PWR_OK from the ATX/ATX12V PSU
- RUN_PG from the CM4
- nRPIBOOT from the CM4
- PI_LED_nPWR from the CM4
- GLOBAL_EN from the CM4
- nEXTRST from the CM4
- WL_nDISABLE from the CM4
- UART pair for config? which?
- i2c/smbus pair for config? which?
- SPI triplet for config? which?
- PWR_LED from the front panel header (is this two wires for bicolor antiparallel LEDs?)
- HDD/ACT_LED from the front panel header
- PWR_BTN from the front panel header
- RST_BTN from the front panel header (note many cases lack this so don't depend on it)
- possibly a chassis intrusion switch
- possibly a wireless-disable switch
- what else?

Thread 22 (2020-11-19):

audio and microphone jack

derwana, 2020-11-19:
One of the things the pi really lacks is good audio in and output. The Pi 4 model B got an audio jack, the IO Board none. But what about a microphone jack, 2.1 sound (or even 5.1). There are some HATs out there doing this by I2S, SPDIF or an HDMI Audio Grabber IC.

Some examples:
[SUPTRONICS ST6000](https://www.audiophonics.fr/en/dac-and-interfaces-for-raspberry-pi/suptronics-st6000-dac-es9023x4-hdmi-24bit-192khz-71ch-for-raspberry-pi-p-11849.html) or [X6000K-7.1CH Expansion Board](http://www.suptronics.com/miniPCkits/x6000-7.1ch.html) they seem to be the same,
[Amplifier HATs by HifiBerry](https://www.hifiberry.com/amps),
[HiFiBerry Digi (digital audio interfaces)](https://www.hifiberry.com/digis),
[Wolfson Audio Card](https://www.element14.com/community/community/raspberry-pi/raspberry-pi-accessories/wolfson_pi)

All these solutions are quite expensive but certainly worth considering for a Desktop PC.

TheGuyDanish, 2020-11-19:
While an interesting proposition, this is slightly felled by price and many of the ideas that were brought up in #3. While we could add things like audio connectors and all manner of fun ports. If we're exposing GPIO to the user (which is the current plan, having the GPIO header in place of a fourth PCI-e slot on the board), it would be up to the user if they'd like to add a board like this. Admittedly with some kind of adapter, most likely.

That said, as always, if others are interested in getting something like this on the board, I'd be happy to hear it.

TheGuyDanish, 2020-11-21:
I just had another thought on this. We have two USB2.0 expansion headers that allow for two ports each. I definitely see a world in which we could sacrifice one of these headers and leave open two ports for integration with whatever might be a neat feature. I know the phrase "USB sound card" probably doesn't inspire much confidence in audiophiles, but it _is_ a solution to adding some audio to the board, and it doesn't use up any precious GPIO pins.

At this point in time:
HD1 & HD2 are the USB ports used for the rear ports in the stacked Amphenol 72309-8014BLF connector
HD3 & HD4 belong to expansion header 1
HD5 & HD6 belong to expansion header 2
HD7 is the internal USB Type A that will be mounted vertically on the board. (Bel-Stewart SS-52100-002 connector)

My thought would be to discard expansion header 2 and leave HD5 and HD6 open for any kind of built-in functions. Anyone have input on this?

dogbreaf, 2020-11-22:
> I know the phrase "USB sound card" probably doesn't inspire much confidence in audiophiles

On the contrary, most audiophiles are going to be using an external DAC anyway since they avoid issues with electrical noise inside the case, and most of those are USB

How are the pi model B's providing analogue audio out? Because it seems like the easiest option (if it doesnt interfere with other planned features) would be to just copy that, and anyone who wants audio input could just use a dedicated USB soundcard or more professional USB audio interface

derwana, 2020-11-22:
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

It is taking the signals from `pwm1_mosi` and `pwm0_miso`, directs them through a bandpass (i think) on to the jack

TheGuyDanish, 2020-12-20:
I'm still more inclined towards a USB solution for this as, to my knowledge, the PWM1_MOSI and PWM0_MISO pins referred to above are actually GPIO pins, and that adding an audio interface like the one on the Pi4 could interfere with the use of those pins. (I'm not sure of this, so please correct me if I'm wrong). But for the above reason, I would personally prefer a USB-based solution that can be 'separate', if that makes sense.

funkyguy4000, 2020-12-20:
It may simplify the manufacturing and help bring cost down if we only offer the audio jack using the PWM pins mentioned above. That will still give a baseline audio option for those that need a simple output a d keep the USBs on the headers. If the user wants a better USB based experience, they can purchase a USB audio adapter. Chances are if they are using a raspberry pi for audio based projects stuff right now, they're using the built in or have an adapter they want already. We shouldn't choose their usb audio adapter for them

TheGuyDanish, 2020-12-20:
Good call on that one. In that case, I think re-implementing the kind of design used in the Pi would probably be suitable.

I'll look into this sometime soon, assuming no one else does it before me. (Trying to get PI7C power done during the next week.)

volkertb, 2021-01-26:
@derwana mentioned an HDMI Audio Grabber IC as one of the possible solutions. I kind of like that. It takes the audio signal already coming out of one of the HDMI ports and converts it to both digital S/PDIF and analog audio outputs.

Considering how devices such as the one shown below [go for a few bucks on Aliexpress](https://www.aliexpress.com/item/32780772075.html), my guess would be that the ICs they are based on are a dime a dozen and can probably be sourced very cheaply.

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

An integrated solution like this would be cheap, wouldn't require us to sacrifice any USB ports, would enable us to add both digital S/PDIF and analog sound output ports, without any of the Pi's native on-board sound playing capabilities posing any quality bottlenecks. The audio coming off the HDMI port(s) is digital after all, right? Also, HDMI audio doesn't have any of the latency problems that you might have with USB audio devices.

Perhaps similarly priced ICs also exist that perform the reverse action (take audio from an analog or S/PDIF source along with an HDMI video input and merge those into a combined HDMI signal that we could then feed into the TC358743 CSI2-to-HDMI bridge IC to provide audio input capabilities from microphone and line-in ports (both analog and S/PDIF) as well.

TheGuyDanish, 2021-02-10:
Moving this to revision 1.? rather than 1.0. I don't see this as being an important feature to the first iteration of the board, as I imagine the kinds of people that would want to get their hands on this in the first couple of runs aren't the type that would necessarily need 3.5mm audio jacks (or would be happy with a USB or PCI-e adapter). I'm still very much interested in getting this implemented, but I think there's a lot of ideas with no clear-cut solution at the moment.

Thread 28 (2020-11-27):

Power wiring for PI7C PCI-e switch

TheGuyDanish, 2020-11-27:
As I've mentioned a couple of times before, there are some parts of schematic and PCB design that I'm not quite confident with.

In the interest of moving this project forward, I'd like to request some assistance from anyone that has experience in designing schematics, specifically around powering ICs with different voltage. (1v, 3.3v, both analog and digital power)

I have requested, and received, a trove of design documents from Diodes Inc regarding this chip (That I am not publicly sharing due to concerns about disclosure). Including application notes, checklists, PCB design guides and a reference board design. I'd be happy to pass this onto anyone who would like to oversee getting the right power wired into this chip.

Alternatively, there is a chance I will be able to look at this around mid-December when I get back to Denmark and have a chance to chat with my father about it, as he's more qualified with these things.

TheGuyDanish, 2021-01-18:
As of fdb83ae, I dare say this is mostly done. I still would love if someone with a background or experience in power delivery could look through the PCI-e sheets and let me know in an issue if something here seems to be off or require adjustment. None the less. One step closer.

Durburz, 2022-01-05:
Although I don't have that much experience in power delivery circuits I would be willing to have a deeper look at this part if you could provide me the documents mentioned. (If all of this is still necessary)

TheGuyDanish, 2022-01-05:
I appreciate it, however @myself248 is currently working on potentially re-doing the PCIe switch section with a new chip in mind. He's in the Discord linked in the README, should you want to ask him yourself. Otherwise I can also point him to here.

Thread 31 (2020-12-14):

pci express lines need ac coupling caps

HaasJona, 2020-12-14:
Should be 0402 size, 0.1µF, and on both lanes at the same position (inside the trace, not to ground).

TheGuyDanish, 2020-12-14:
This would be good to add whenever we finish wiring up the PCI-e ports. I've currently only done to the preliminary signaling work, I'm still figuring out how to do power delivery and so forth. That said, if you'd like to do this, I'd be more than happy to accept pull requests for it.

funkyguy4000, 2020-12-28:
I've started wiring this up. Keep in mind that the AC caps on the motherboard will only be on the TX lanes per the PCIe specification and PCIe design guidelines.

TheGuyDanish, 2020-12-30:
Closed as of b87e19b

Closed 2020-12-30.

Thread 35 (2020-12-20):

Atx12vo

ldrrp, 2020-12-20:
I dont mean to toss some logs into a fire but perhaps considering the pi is known for efficiency. We adapt the new trend of atx12vo power supplies. They tend to be cheaper and more efficient naturally since they only  dish out one voltage. Im not saying drop the normal atx only but maybe a variant board on the repo that could be kept in line with the main board with the exception of the power circuits.

If thats seen as not needed or wont do please close this or comment your thoughts so others know.

TheGuyDanish, 2020-12-20:
ATX12VO has crossed my mind when I was doing the initial legwork on this. Though since it hasn't proliferated as much yet among DIY builders. (Which I imagine will be the primary users of a board like this) I think sticking to regular ATX is the best bet for now.

That said, I think once we get to a point where we have a board in a higher revision, once everything is wired up, I'd be happy to look into the possibility of creating an ATX12VO branch. (Or if someone else wants to do this work now, they are welcome to present it)

Adding future revision label.

ldrrp, 2020-12-20:
This makes perfect sense. I can agree with branching at a higher revision as well.

TheGuyDanish, 2020-12-28:
Closing this in favor of #46 to clean up current issues.

Closed 2020-12-28.

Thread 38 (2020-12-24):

Errors in RJMG2012119A0NR.stp

derwana, 2020-12-24:
The STEP file `RJMG2012119A0NR.stp` is kind of odd. Footprint and device do not match (through holes do not align with pins).

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

TheGuyDanish, 2020-12-24:
Looking into this, it appears to be an oversight of mine, more than anything. Rotating the device to fit on the bottom, rather than on top of the board, the 3D model aligns perfectly with the pins, so perhaps, this specific SKU was meant to be mounted to the bottom of a board.

Regardless, I'm still not sure I'm a fan of this port. RJ45 jacks have in general been the bane of my existence for the last little while. The previous one used in the design, the one by Bel-Stewart was 100 Mbit/s, which is why I replaced it. This one matched the description of having an on-board transformer, being gigabit and not having extra cost from being a PoE part.

I'll have a look at other potential parts available on Mouser and update the design with one that fits the board a little better, hopefully today or tomorrow.

(Merry Christmas to those celebrating, by the way.)

TheGuyDanish, 2020-12-24:
Think I got a proper candidate.

ARJM11C7-502-AB-ER2-T

https://abracon.com/Magnetics/ARJM11.pdf
https://www.mouser.co.uk/ProductDetail/ABRACON/ARJM11C7-502-AB-ER2-T/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

TheGuyDanish, 2020-12-24:
Only slight gripe with this was that I couldn't find a detailed 3D model anywhere on Abracon's website. I'm sure one exists somewhere on the Internet, but I'm not fussed enough to find one at the moment.

Closed 2020-12-24.

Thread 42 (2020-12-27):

voltage of GPIO_VREF not defined

derwana, 2020-12-27:
GPIO_VREF is used on sheets (1,) 2 and 6 but never defined.

Screenshots from CM4_IO:
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

TheGuyDanish, 2020-12-27:
J1 on CM4_HighSpeed
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

I do want to potentially make this a solder jumper to 3.3v by default.

TheGuyDanish, 2020-12-27:
Actually, disregard. Just read that schematic again. Yes, we do need to establish VREF voltage. Perhaps via the aforementioned jumper

Closed 2020-12-28.

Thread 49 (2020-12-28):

Implement Real Time Clock

TheGuyDanish, 2020-12-28:
As mentioned in #1, we can quite easily implement an RTC into our design (which I believe would be a genuinely nice and useful feature). I'm breaking it out into a new issue to increase visibility.

> On-board RTC is present in the CM4IO board and could easily be lifted if we want to integrate it.
> 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
> 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
_Originally posted by @TheGuyDanish in https://github.com/TheGuyDanish/CM4_MATX/issues/1#issuecomment-727240965_

TheGuyDanish, 2020-12-29:
Looking further into this, I think using the NXP [PCF85263A ](https://www.mouser.dk/datasheet/2/302/PCF85263A-1127483.pdf) instead would be a better call. It has built-in circuitry for switching to battery power, meaning we can power the RTC with 3.3vSB when the power supply is powered and a coin cell battery when it isn't.

derwana, 2020-12-30:
I'll take a look into it an do a schematic etc. in the new year.

TheGuyDanish, 2021-01-06:
Closed by #51

Closed 2021-01-06.

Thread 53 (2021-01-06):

heat sink for CM4

garlick, 2021-01-06:
Has heat sink mounting been discussed for this board?

I've looked around and not found much offered specifically for the CM4, but I have made contact with  [Alpha Nova Tech](alphanovatech.com) and requested some help fitting one of their products to a CM4 for another project.  Right now it's looking like M2.5 shoulder bolts and press-fit PEM style threaded inserts, with an off the shelf heat sink, custom drilled for the CM4 will be the most economical solution.

Would appreciate any insight others have here, and of course will share what I learn if that's helpful.

geerlingguy, 2021-01-06:
With active cooling (e.g. a fan anywhere in the case), I haven't had any trouble keeping my CM4 from throttling. For other Pis, I typically just use a little heat spreader like the ones that come in most cooling kits, that's about the dimension of the chip itself, about 3-5mm high.

garlick, 2021-01-06:
Good to know!  Maybe it won't be a problem here.

TheGuyDanish, 2021-01-07:
My initial thought with this was to just use the mounting holes that are already on the CM4. The Turing Pi 2 already illustrates a heatsink design that uses those mounting holes, and I imagine solutions for them (perhaps with a plastic backplate and screws on top, like a regular CPU cooler) will appear in time.

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

Alternatively, if someone just wants to put a single small heat spreader/heatsink on like Jeff does, I think that should be fine as well. My main concern with regards to cooling is just getting airflow through the case.

garlick, 2021-01-07:
Yeah this Turing Pi pic is what I sent the Alpha Nova Tech guy as a starting point.  Apparently a normal PCB thickness (1.6mm) is not sufficient thread depth for those shoulder screws, hence the recommended inserts., but guess a backplate could do the trick too if there's enough room under the board.

TheGuyDanish, 2021-01-07:
>if there's enough room under the board.

It would need a bit of engineering to make a custom solution, but most cases sold these days have some room (or even a full cut-out) behind the CPU specifically for easy backplate mounting. The typical Noctua one is not much thicker than 3-4mm, putting the mounting pegs up through the holes for you to screw the cooler down onto.

This shows what I mean fairly well: https://youtu.be/3qq9syfjxc8?t=137

mo-g, 2021-01-14:
I guess the only thing that @TheGuyDanish would need to make sure here is that there were no components standing proud under the board where the SOM mounts, and that some large diameter holes for a backplate's studs are available.

After that, assuming the PCB thickness of this board matches other people's PCB thickness, anyone elses' heatsink solution for the CM4 should be a drop-in.

derwana, 2021-02-10:
[Elecrow](https://www.elecrow.com/heatsink-for-raspberry-pi-compute-module-4-cm4.html) and [AliExpress](https://de.aliexpress.com/item/1005001933362417.html) now offer some heatsink(case)s for the CM4.

TheGuyDanish, 2021-06-02:
Update to this, as expected, coolers that use the default CM4 mounting holes are starting to show up around the internet, with a couple of examples like these:
https://www.waveshare.com/cm4-fan-3007.htm
https://www.waveshare.com/product/cm4-heatsink.htm

Seeing as these are pretty naturally fit for the topic, I don't believe there's a reason to keep this issue open for now.

Closed 2021-06-02.

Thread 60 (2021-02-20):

How hard is/was this project to implement?

bhansconnect, 2021-02-20:
This isn't really an issue, but I was hoping to get some input because I am interested in doing something similar as a hobby project.

Just in general, how hard is it to build a board around the CM4? I would assume that if you stay within the default functionality it is relatively simple, but adding things like a PSU, DAC, or chips on the PCIE bus greatly increase the complexity.

What would you say are the hardest parts of designing this board? Any specific major issues you faced?
Have you gotten to the point of manufacturing any tests PCBs?  Have you been picking components specifically thinking about manufacturing?
Is there anyway for you to test things before manufacturing a PCB? I assume simulation of this with many black box chips would be extremely hard. Is the only option lots of schematic review to hopefully catch bugs?

Sorry for the barrage of questions, I am just hoping to learn more about the challenges of this sort of process.
Thanks for your time.

TheGuyDanish, 2021-02-20:
TL;DR:
- While it requires some serious thought, practice and math. If a more skilled electrical engineer were to lead this project, they would likely have finished a first prototype and be bordering on a shipable product by now.
- The project would greatly benefit from an easy way for a home user to manufacture and assemble a board that uses these incredibly tiny and difficult to solder components, or access to someone with the necessary facilities to do this.
- To the above point, getting a board manufactured is the most inexpensive part. Home assembly could be done given a stencil and a reflow oven (a small model of which likely wouldn't be of great difficulty to acquire). This is something I might look into, but as I'm currently planning to move out of London, it'll be pending my arrival in my new home.

Let me know if any other questions arise from this and I'll be happy to answer.

---

I'll preface my answer to this with the following: I am by no means a qualified electrical engineer and have only a small bit of experience with schematic design, and less with actual PCB routing. My experience is purely self-taught, though I have a grasp of basic electrical theories (Ohm's law, etc), mostly with regards to mains voltage work, logic gates and some Arduino-style microcontroller programming. With that said, I believe in the sort of maker/hacker ethos that is "No matter who you are or what your experience level is. Somewhere, someone doing what you're doing in a professional capacity is bodging shit the exact same way you are."

Onto the actual answers, though.

> Just in general, how hard is it to build a board around the CM4?

My honest opinion on working with the CM4 so far (without having had a board I've designed in my hands yet) is that it seems easy on the surface, but I'm waiting for any small 'gotchas' to show themselves. The CM4 has excellent documentation and the IO board is an amazing resource for drawing examples from. A lot of schematic work here has been largely inspired by, if not lifted from, the CM4 IO Board's open source design files.

I think the difficulty does increase when you try to add in things that have a certain standard or perceived idea of how they should work. The example of ATX-style power control comes to mind. Everyone knows how a power button on a PC, ideally, should work. However implementing that functionality without the use of a microcontroller is a challenge, especially if you're not 100% up on your ins and outs of 555 timers. In newer motherboards, the signal from the power button "disappears" into the chipset, which is a black box for all we know.

I genuinely don't think the addition of the PI7C PCI-e switch chip has made the design more complicated. The chip is well-documented and within an hour of sending them an email, the manufacturer of the chip (Diodes Inc) sent me a full design kit. It contains a bunch of useful information including a reference board design using the chip, as well as several guides on PCB routing for PCI-e that is useful for more than just that chip.

> What would you say are the hardest parts of designing this board? Any specific major issues you faced?

By far, my biggest issues with this board are my insecurities around prototyping it. As someone who doesn't have a great deal of practical experience designing boards, I would love to test the schematics put together for this project. However, because of price (and part complexity), most components are surface-mount devices that are pain in the neck to solder by hand. Not saying it is impossible, not at all, but a challenge.

In theory, it would be possible to grab a schematic (let's say the PCI-e portion, or the USB hub) and send it off to a manufacturing house (PCBWay, for example) and have them assemble a prototype board specifically for that portion. But at that point, we would need to design a new board with just the parts we want to test, send it off to have it made and assembled, then shipped to someone who can test it. I actually do think this would be beneficial, as I am only able to dedicate a small amount of time to this project a week, so it wouldn't impact the overall timescale.

I'll continue to answer this question in the next section as well.

> Have you gotten to the point of manufacturing any tests PCBs? Have you been picking components specifically thinking about manufacturing?

Not yet. I have, by myself, created some test boards for a few individual features, but there is no "CM4_MATX Prototype Board" in existence at the moment. The main reason for this is because of the number of parts on the board. If we were to assemble this board as it stands right now, I estimate we would be looking at $50-80 in just parts. On top of that we would pay a, comparatively, small charge to have the board made, and another charge to have it assembled. This is why I'm hesitant to make a prototype board before I have a state I'd like to "lock", in effect, and show to an engineer that can tell me any obvious concerns. I don't want to sink between $200-400 into making 2-5 boards that will have a defect that would have been spotted by a more senior engineer.

With regards to components. Most of the named components in use on this board (fan controller, PCI-e switch, USB hub, etc) were picked mostly to match a use case. We want a feature-rich board with cost coming in second. This doesn't mean I want the most expensive parts I can get, but any part with a good reference design or usage examples is a plus for me. The exception to this are near-passive components like a voltage regulator. In truth, I don't care what voltage regular creates the 1.0v or 3.3v rails in this project. The ones that are in the project now were simply picked from Mouser to get one. Is there a cheaper option that would be just as good, if not better, than the ones we have? Likely. Would I swap out our components if it meant decreasing the component cost by more than 20 cents per component? Absolutely.

> Is there anyway for you to test things before manufacturing a PCB? I assume simulation of this with many black box chips would be extremely hard. Is the only option lots of schematic review to hopefully catch bugs?

SPICE is a framework specifically for the simulation of electrical currents and some, simple ICs. It could technically be used, but it would answer questions that we could answer using theory to a high degree of certainty, making it redundant anyway.

Schematic and board review from experienced engineers is very likely the best option, but it is a very time-consuming process. If I were to hand off this board to a friend of a friend who is qualified to look t this, they would need to find our parts, pull up the datasheets, look at the ratings and values and then give their best guess based on that information and prior knowledge about if it would work or not.

Aside from getting hands-on with the board itself, there are very few ways to actually catch a complicated issue before it shows itself on real hardware. This is also the reason why the first run of boards for this project will be very, very limited. Even if people are passionate about this as potential platform, I don't want people to sink money into buying a board that might have an obviously overlooked defect.

TheGuyDanish, 2021-02-20:
As you mention being interested in starting hobby projects yourself, I'd encourage you to walk in the footsteps of others first. One of my first fully-assembled PCBs is a USB to RS232 adapter using an FTDI FT232R chip. It has been done more times than we can count, but it is a useful exercise in both schematic design and PCB layout (especially if using a level shifter).

If you're doing projects that can use mostly through-hole components, but **needs** a few really small SMD ICs, you could use a manufacturing house to get a board with only the SMD parts populated, then do the rest yourself. If your SMD part doesn't have hundreds of pins, you could even break it out into breadboard-compatible 2.54mm (100 mil/thou) pins.

bhansconnect, 2021-02-21:
Wow, thanks for the super detailed response.
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
bhansconnect, 2021-02-21:
As a side note, I recently became aware of the pikeeb project, which is definitely similar in goal to what I want to do, but much larger and bulkier at a minimum. I guess I would be designing a lot of similar hardware though.

TheGuyDanish, 2021-02-21:
I think if you're looking to seriously get into board design, forking out the $200 or so for an infrared reflow oven on ebay is a good investment. Alternatively, you can also get a hot air gun, which should be suitable for simple reflow tasks, which is probably what you'd be doing with smaller/prototype boards anyway. If you can keep a board below a certain size, you could easily get five boards and a stencil for < $30-50 from JLCPCB. Of course, there will be some manual assembly, but as hobbyists, I think spending time with our projects is just part of the fun of it.

From a first reading, your board idea does make sense, and I do definitely think it is quite doable. Seeing as the Pi has onboard ethernet and USB (which you'd likely need to route to a USB hub) the most you'd probably have to think about is the LCD connection and the charging circuit, definitely.

Given the HDMI is exposed as just signals, you could repurpose another connector (say something similar to the flat connector used by the DSI header) to carry the signal to compatible display. You could also find a DSI-compatible display, but I read that most modern LCDs will require more than two pairs of data lines (which is all we've got per DSI header on the CM4). I'm almost certain there exists a good battery solution already using Li-Ion batteries. The theory is all out there, it just needs to be assembled.

All in all, it sounds very doable, and I think one of the best ways to see it through to reality is just to start tinkering. Find the bits and pieces you want, make an outline of what ports you'd like to have on-board and what ICs you'd need to implement them and go from there. Get the ICs, get some reference designs, make a schematic and make a demo PCB that uses a CM4 and that schematic information.

If you're using Discord, there's a link in the Welcome post in the discussions forum with a server I use to chat about this project. Feel free to join and shoot me a DM if you'd like to go over ideas, I'd be happy to contribute my help whenever possible.

bhansconnect, 2021-02-21:
I'm not sure I know which Welcome post you are talking about. Could you share a link?

TheGuyDanish, 2021-02-21:
[This one](https://github.com/TheGuyDanish/CM4_MATX/discussions/29)

> 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

TheGuyDanish, 2021-03-01:
Closing this off for now as I think the question has been answered.

Closed 2021-03-01.

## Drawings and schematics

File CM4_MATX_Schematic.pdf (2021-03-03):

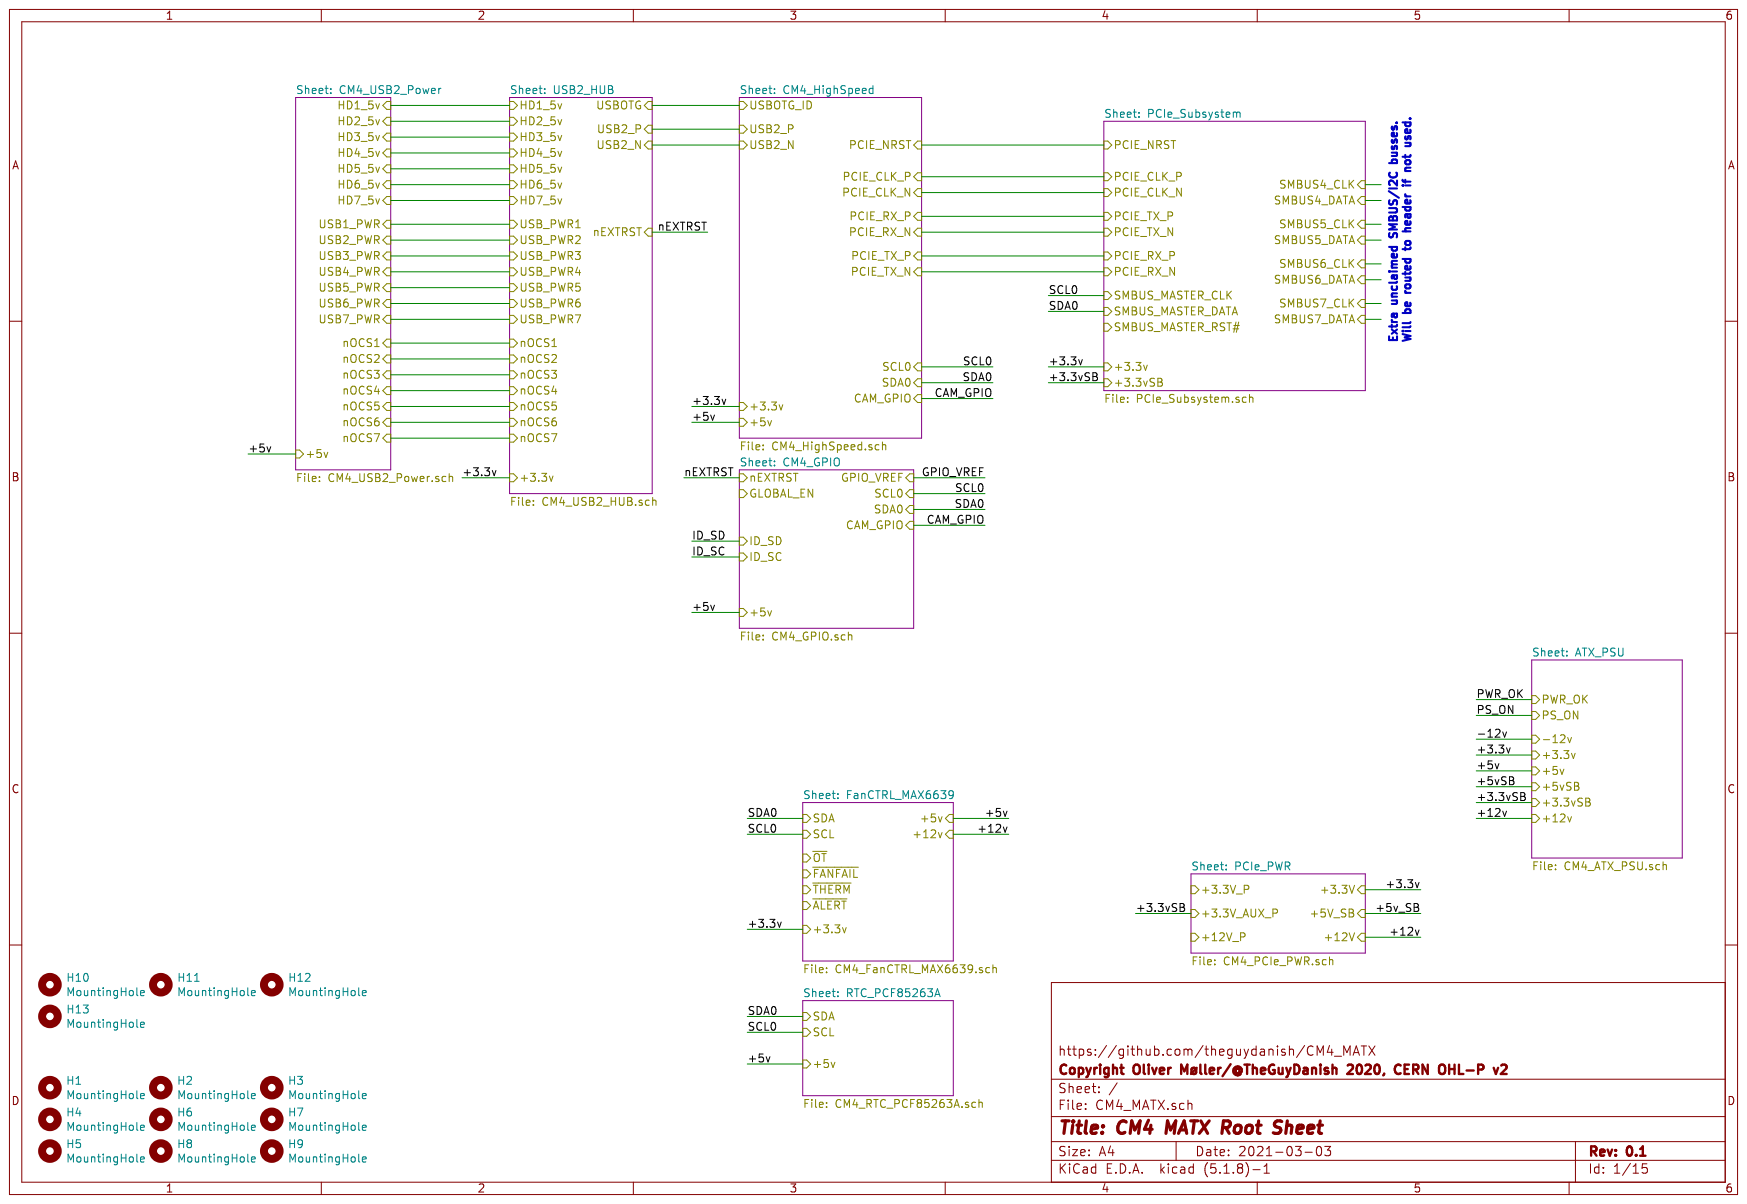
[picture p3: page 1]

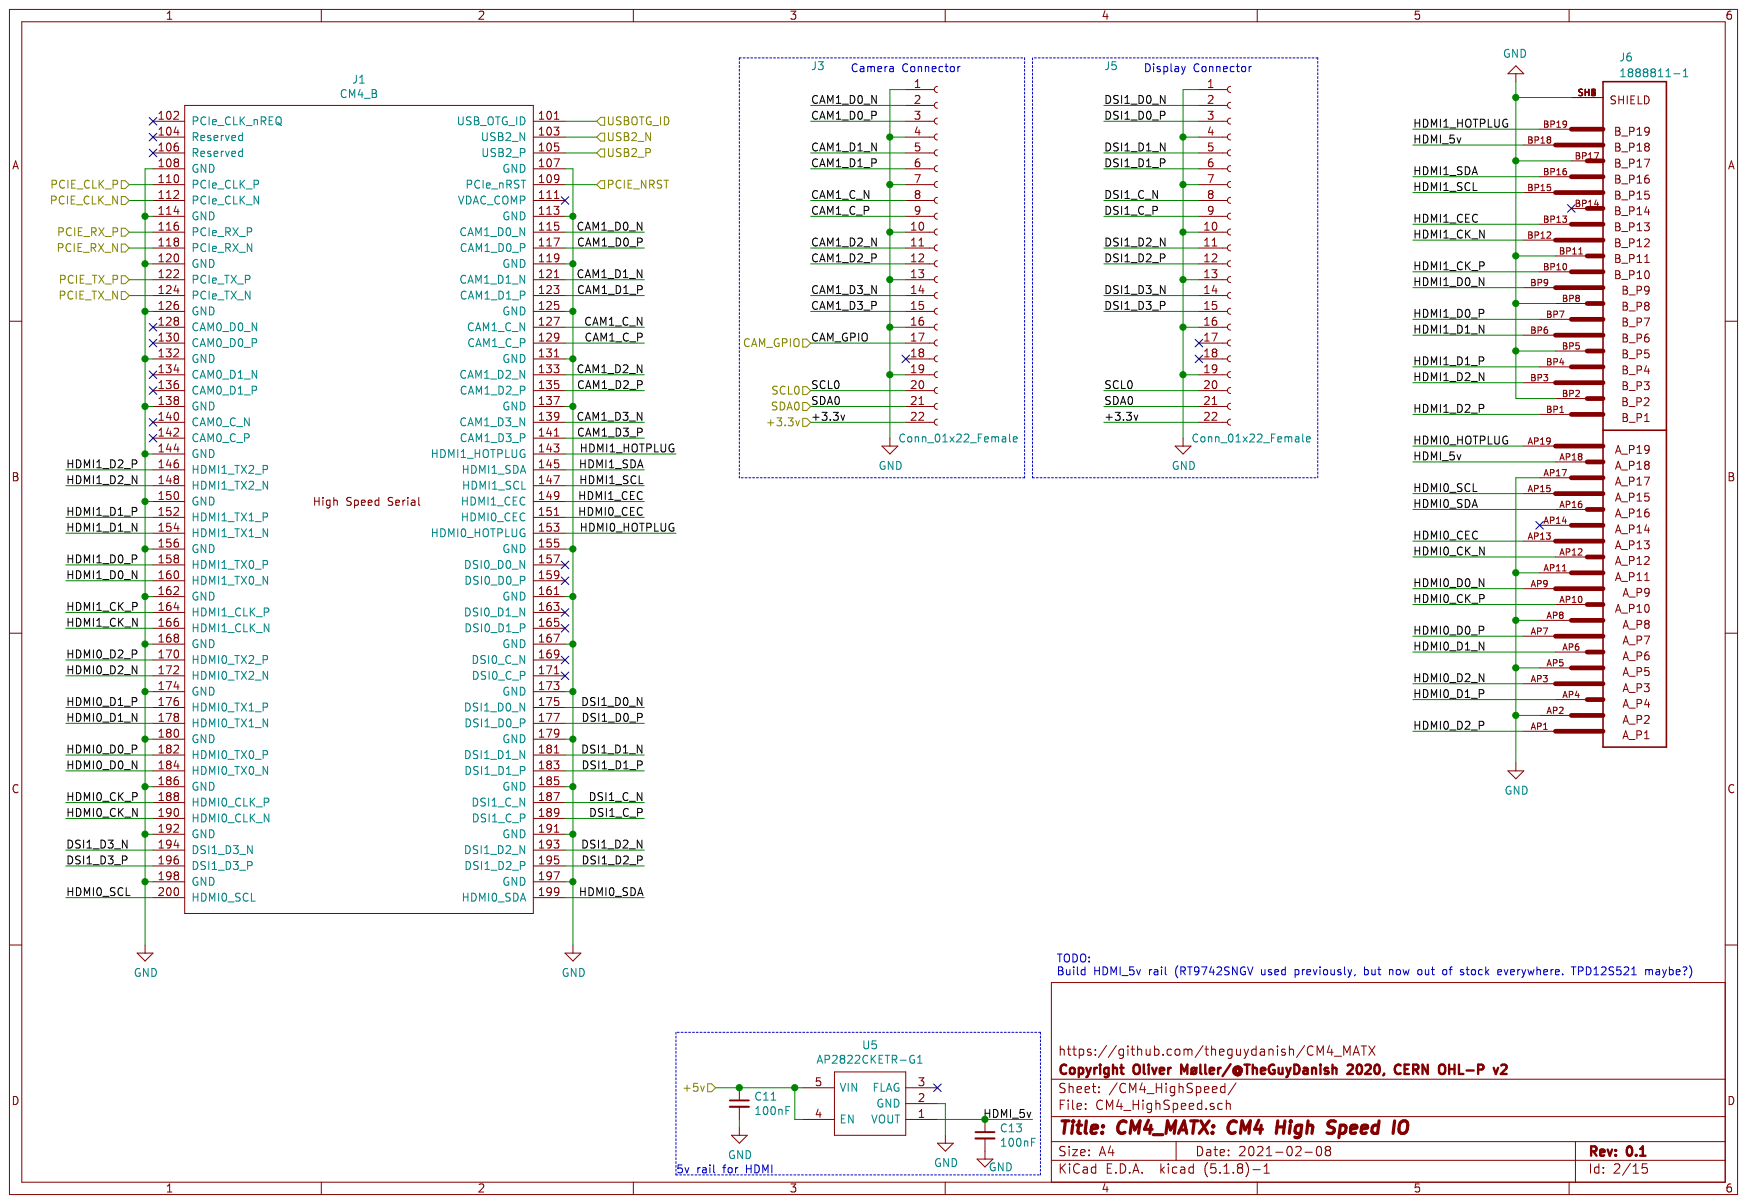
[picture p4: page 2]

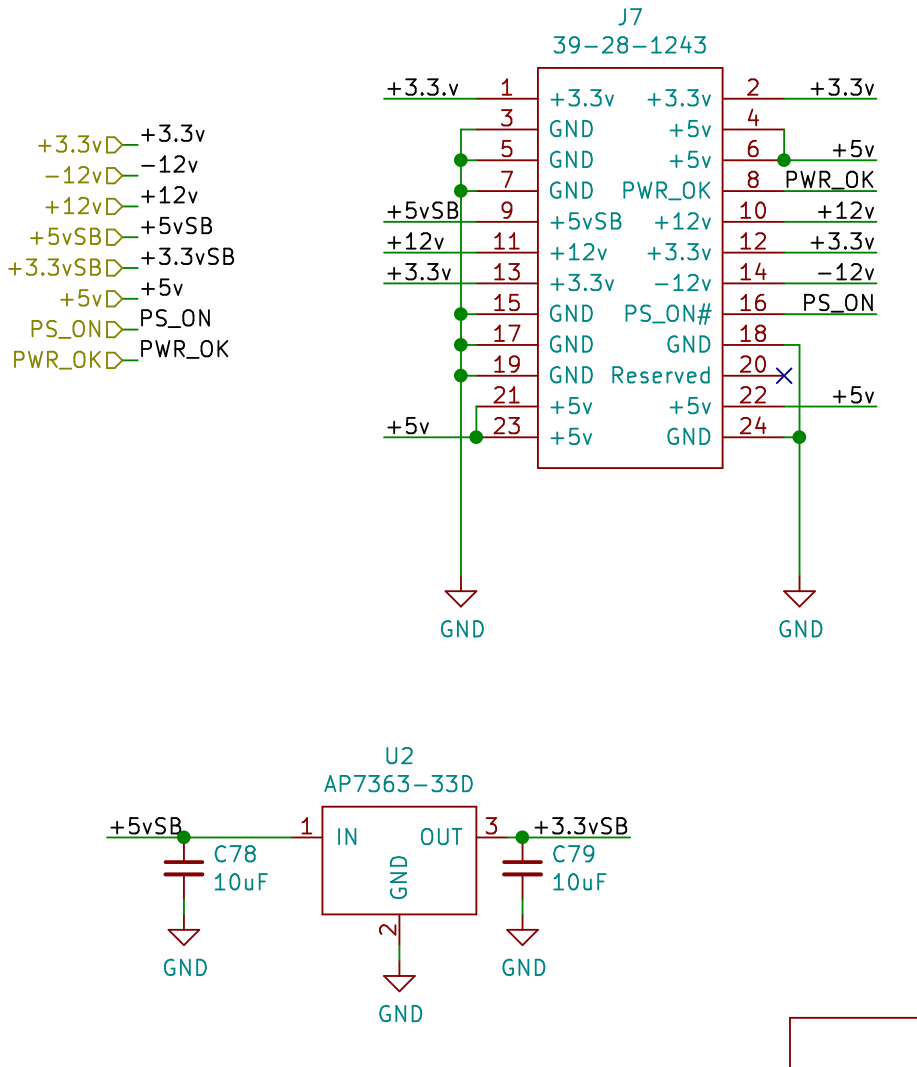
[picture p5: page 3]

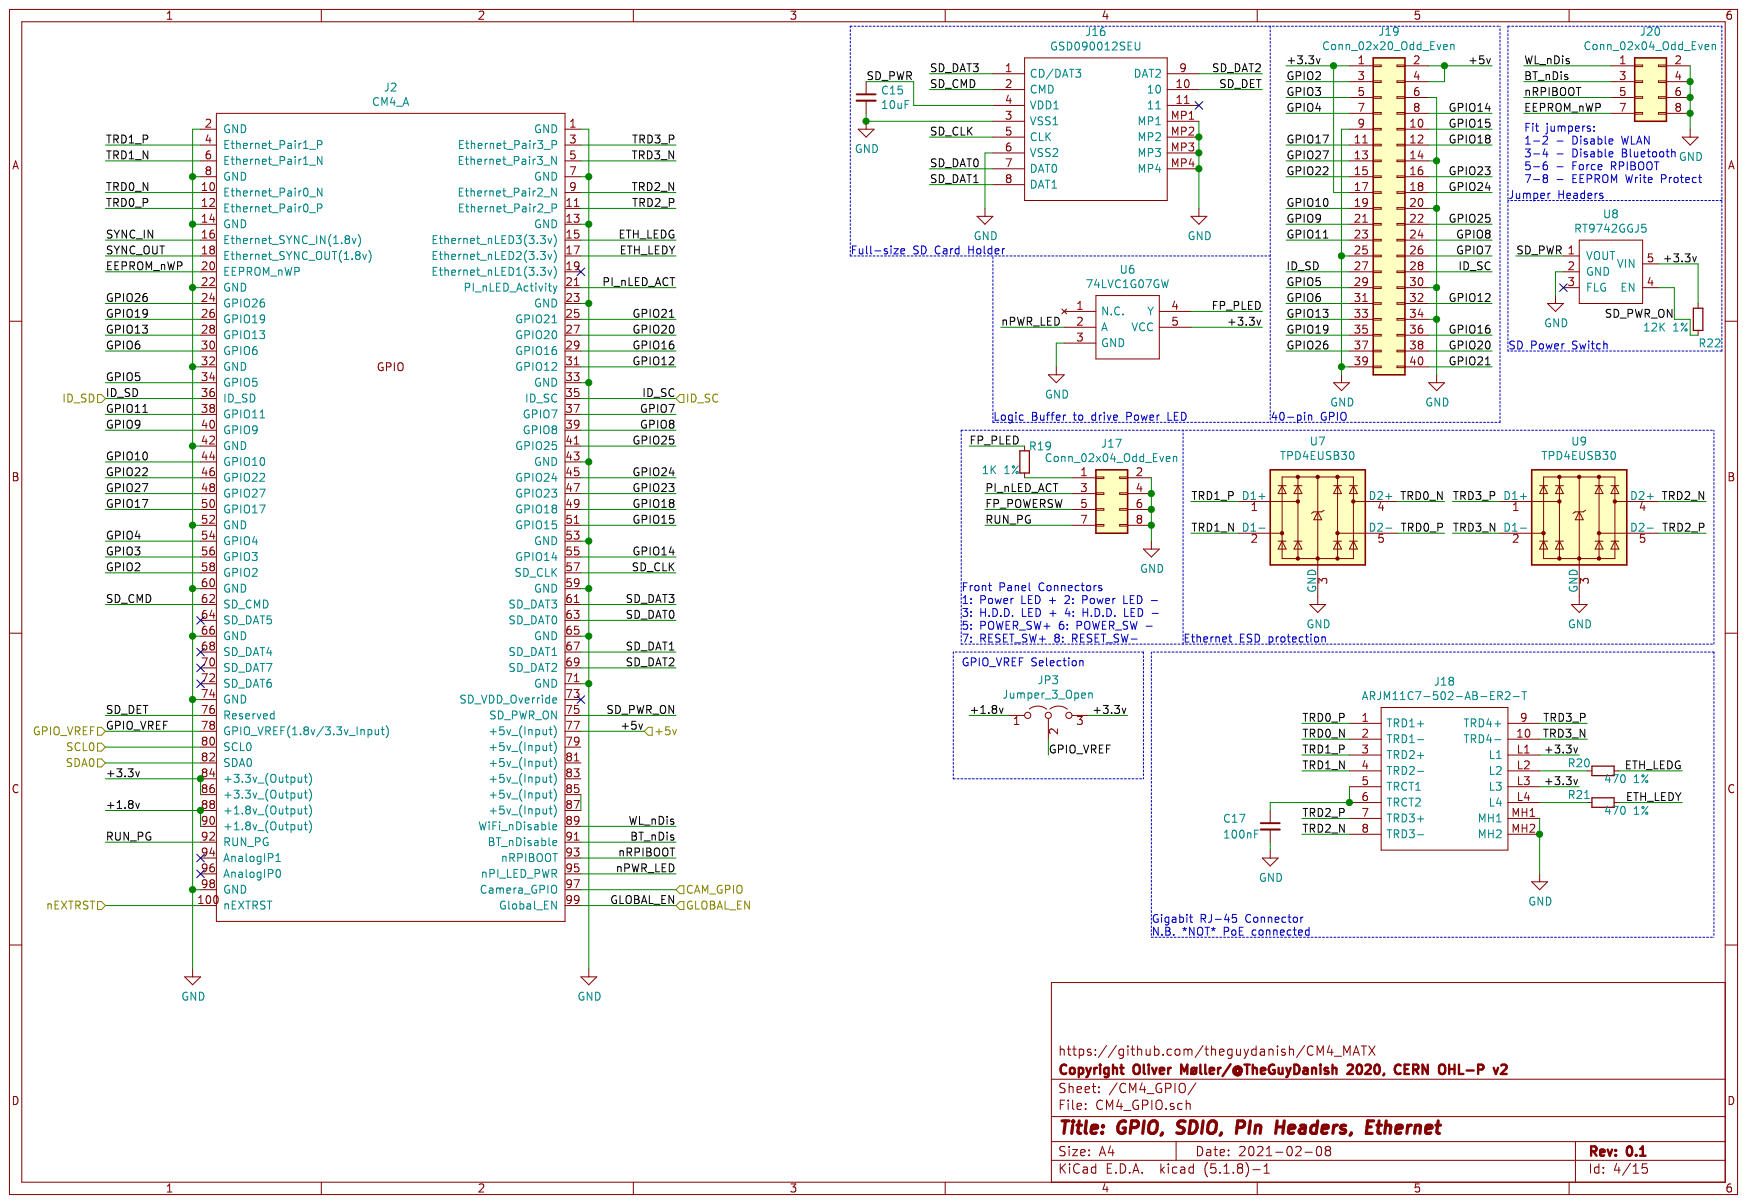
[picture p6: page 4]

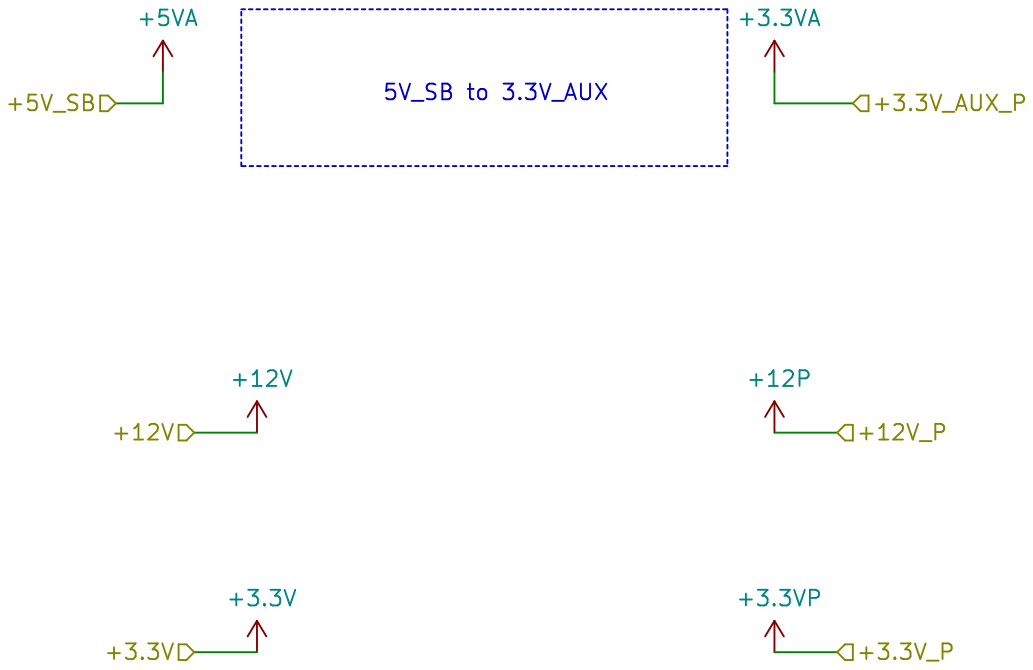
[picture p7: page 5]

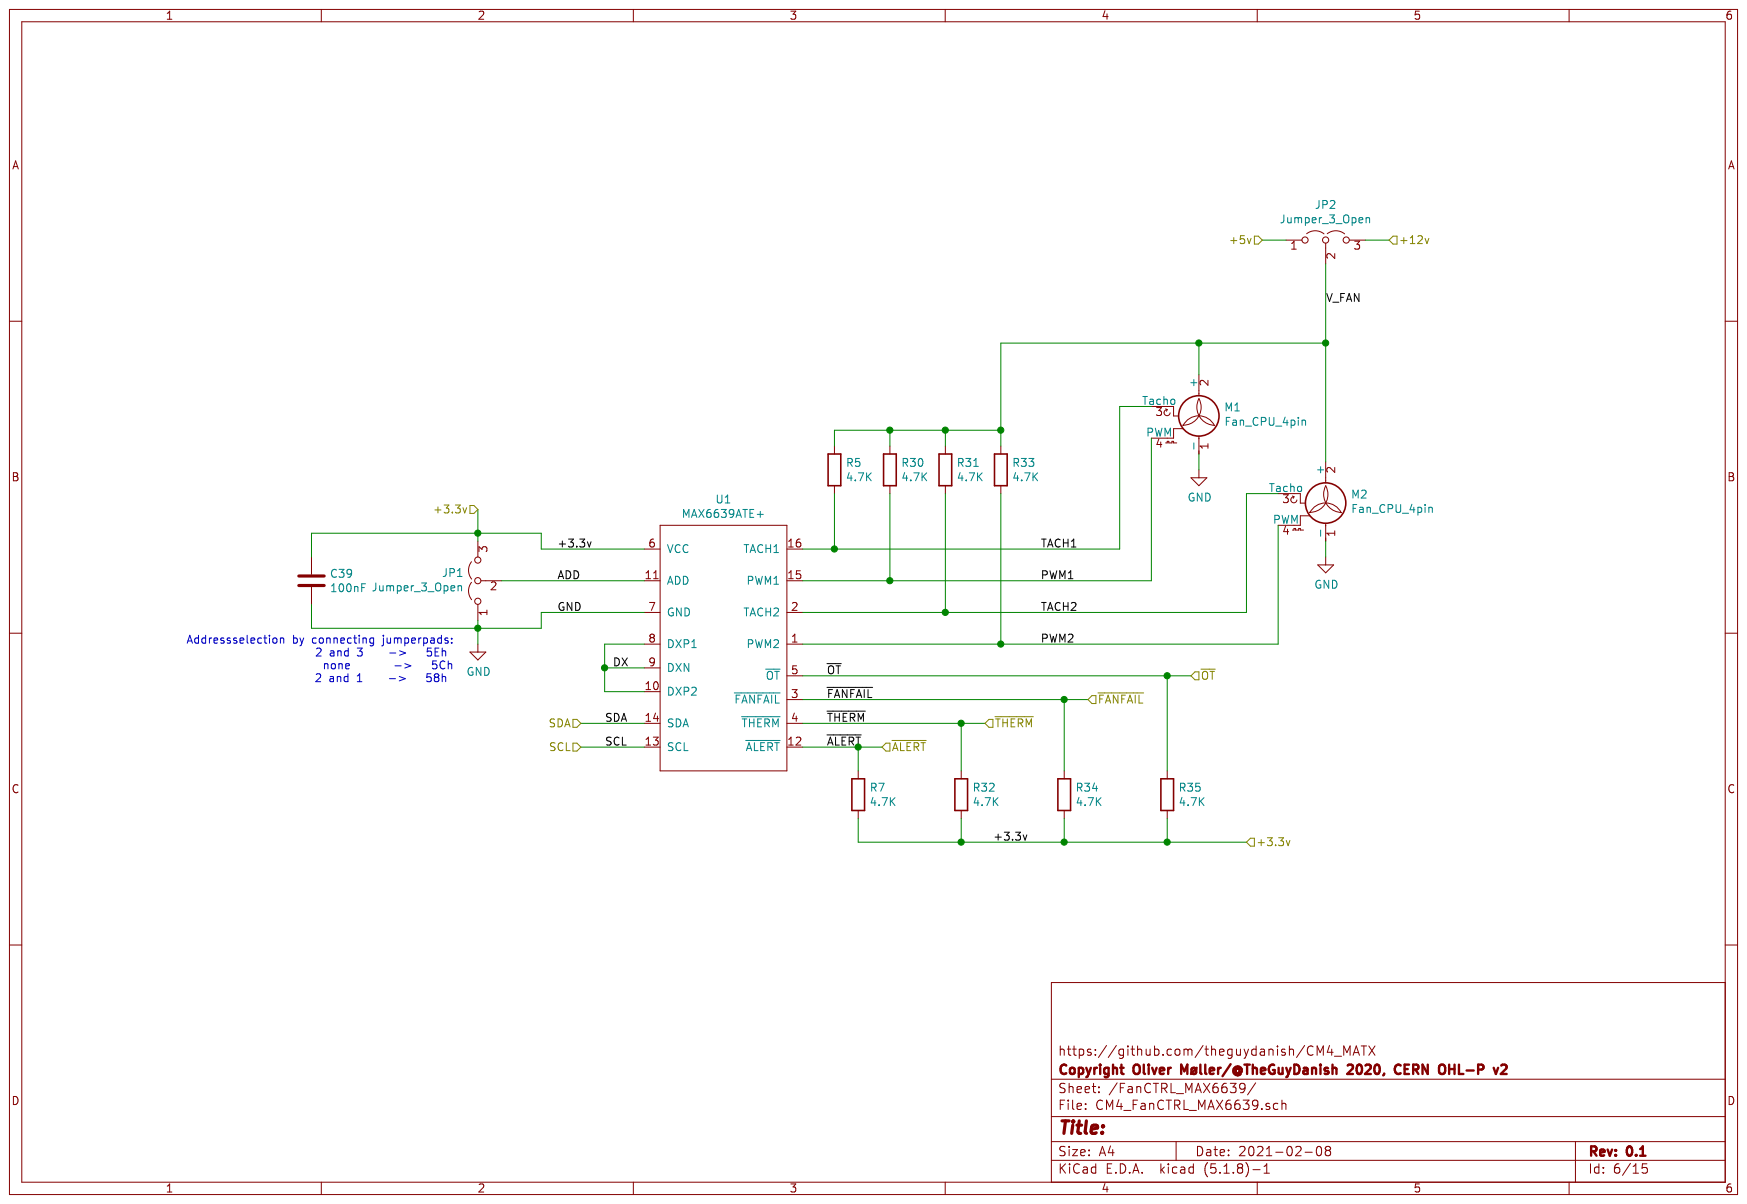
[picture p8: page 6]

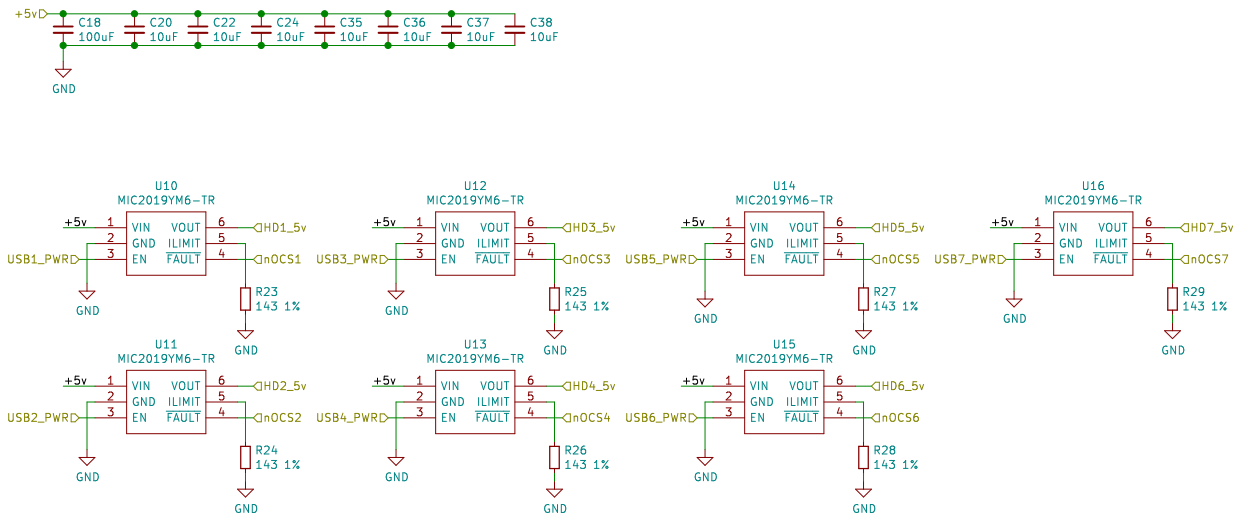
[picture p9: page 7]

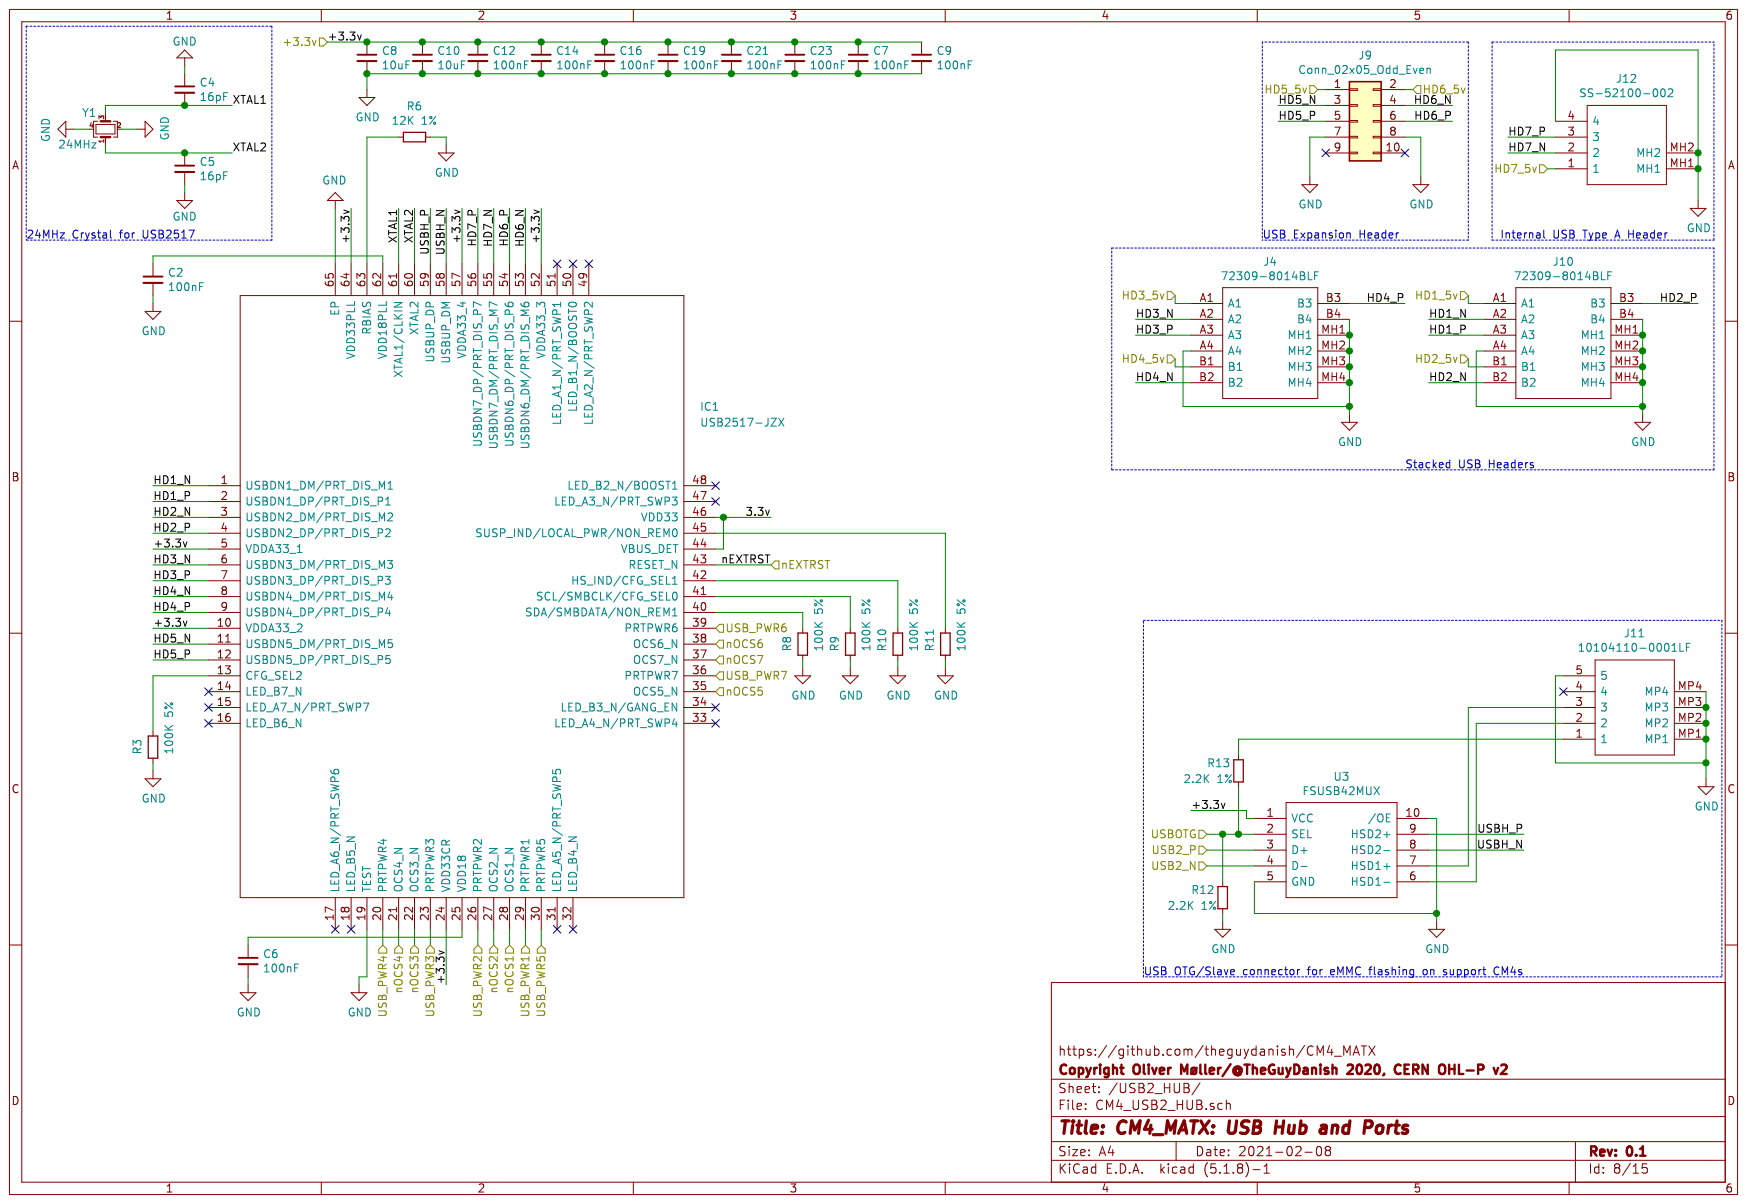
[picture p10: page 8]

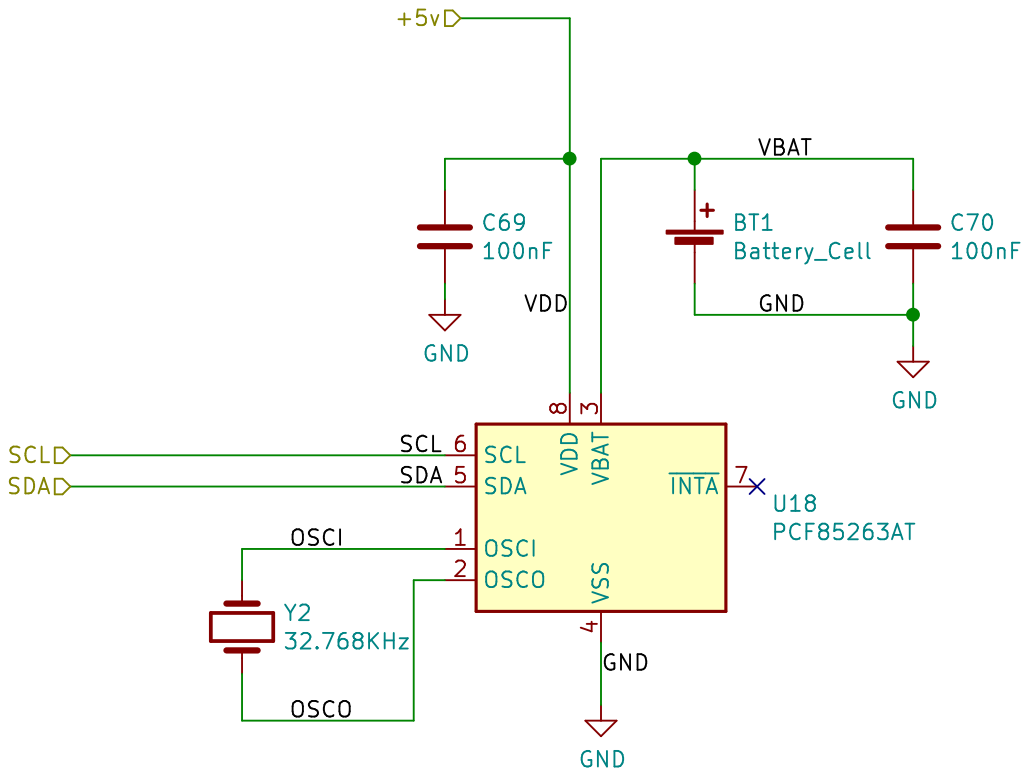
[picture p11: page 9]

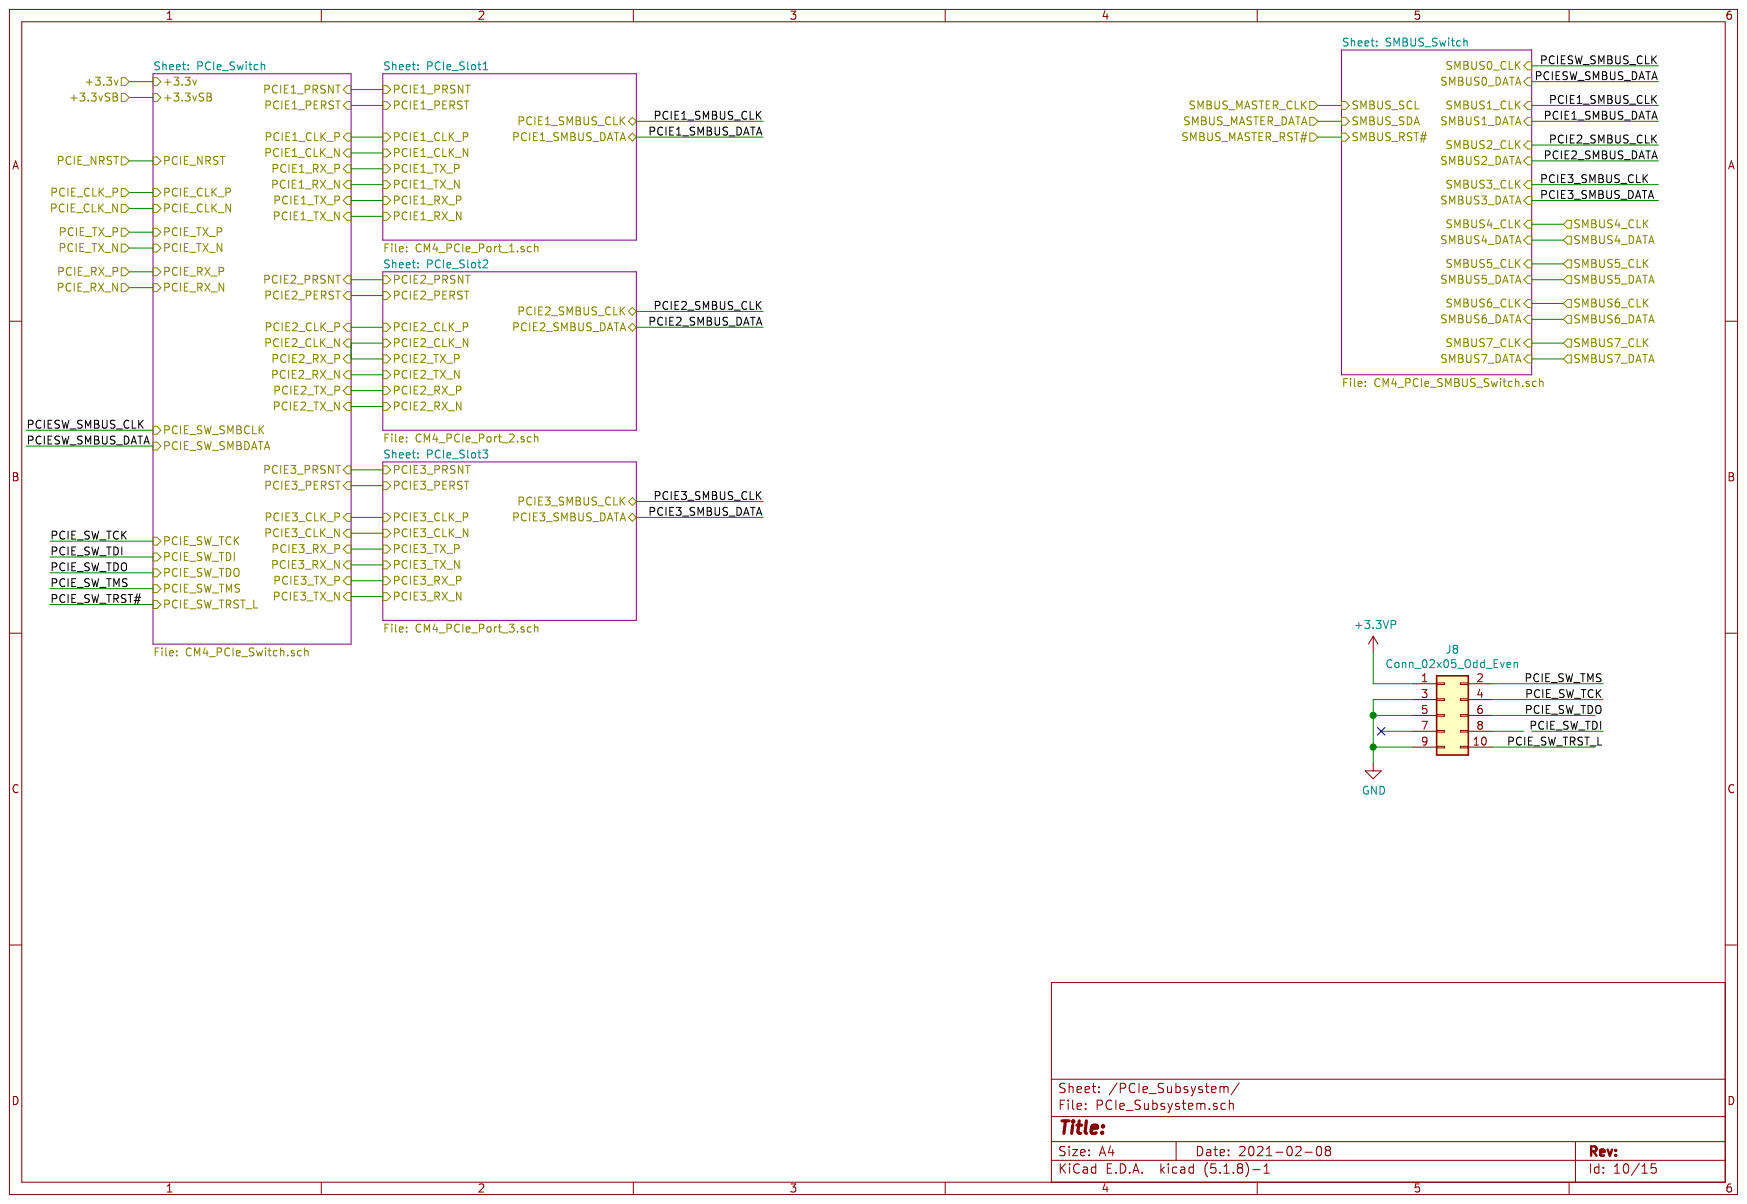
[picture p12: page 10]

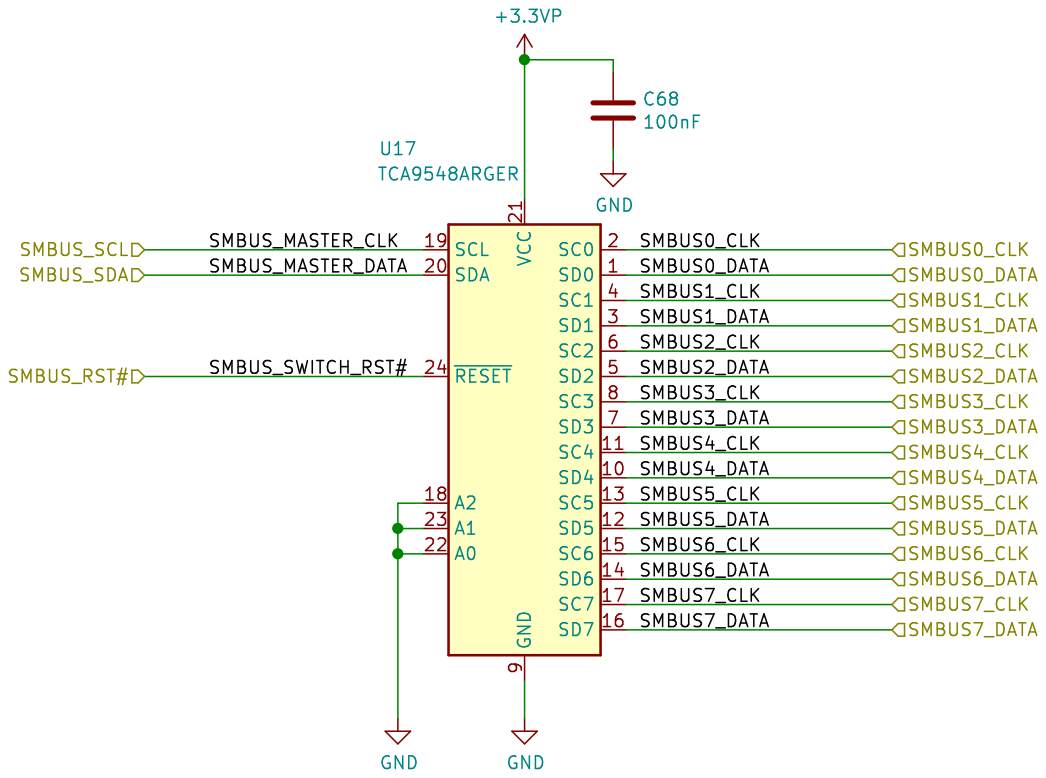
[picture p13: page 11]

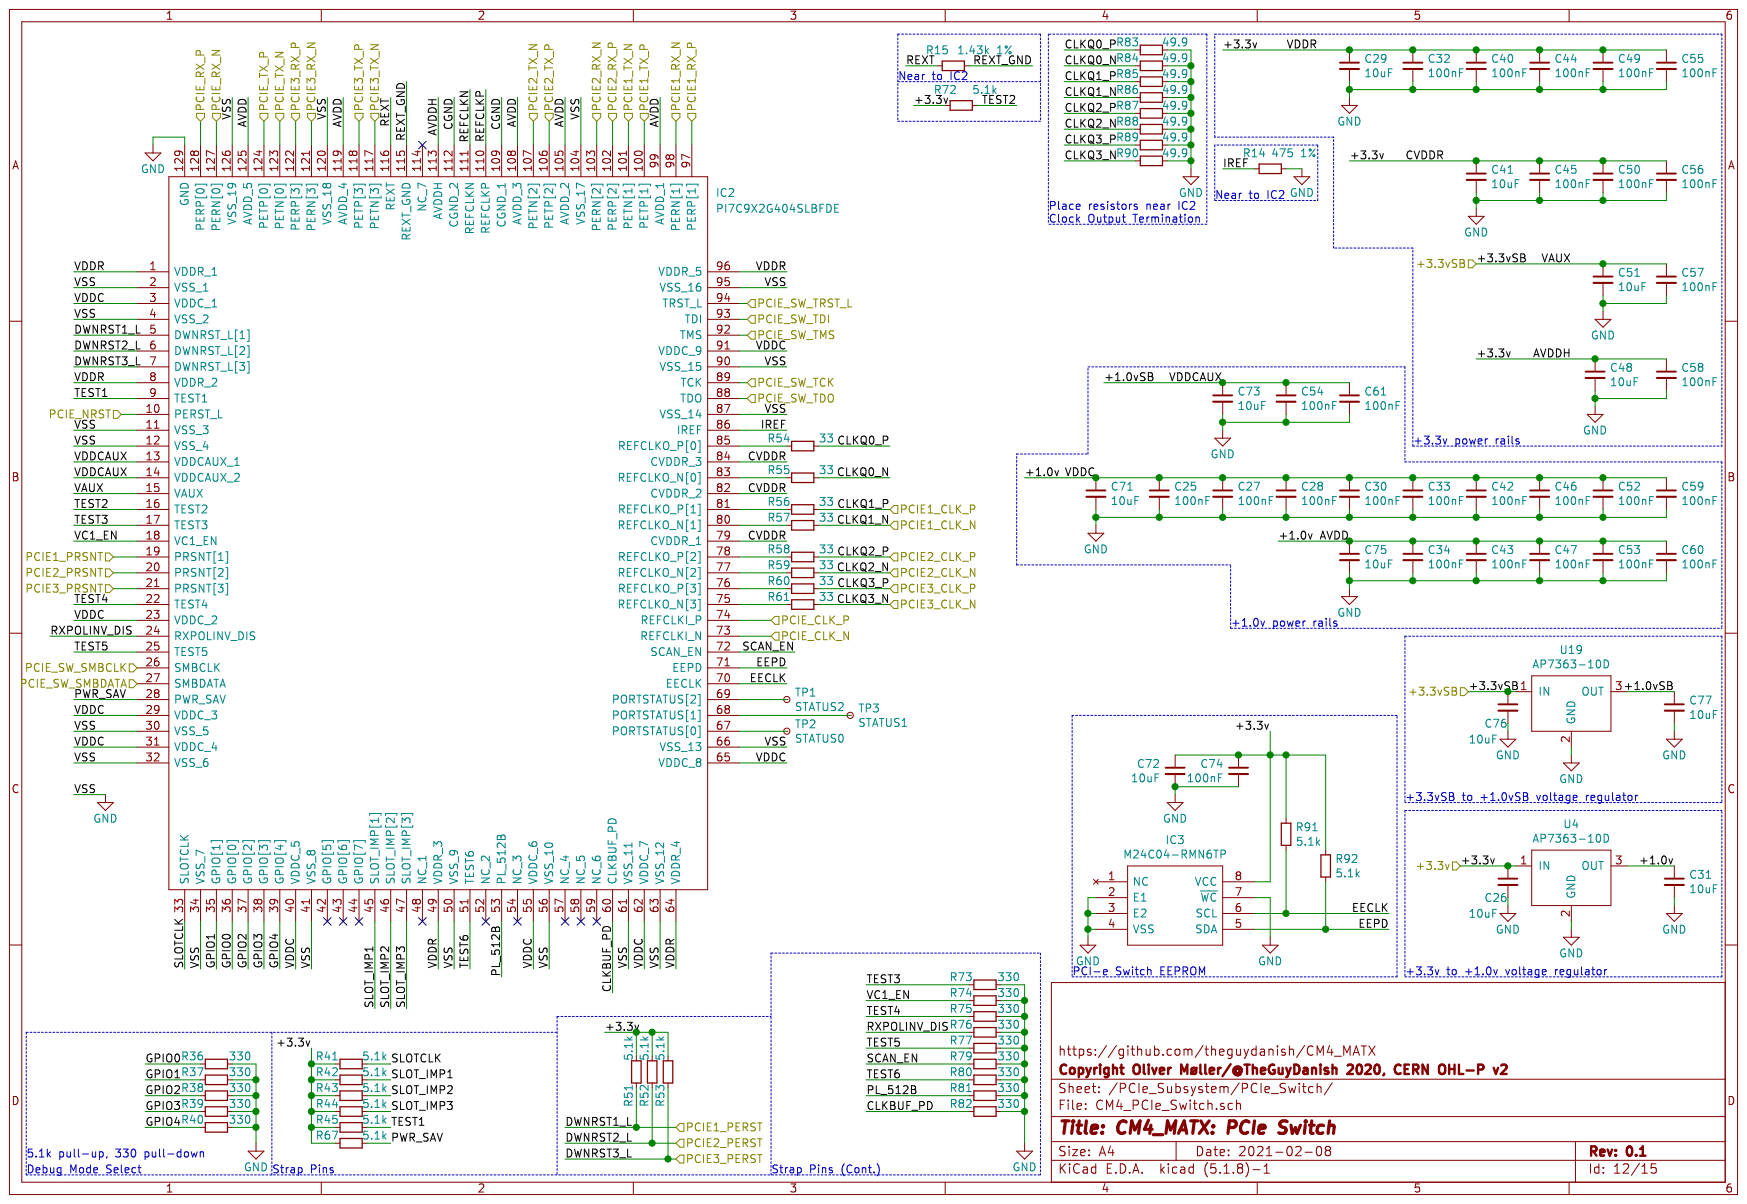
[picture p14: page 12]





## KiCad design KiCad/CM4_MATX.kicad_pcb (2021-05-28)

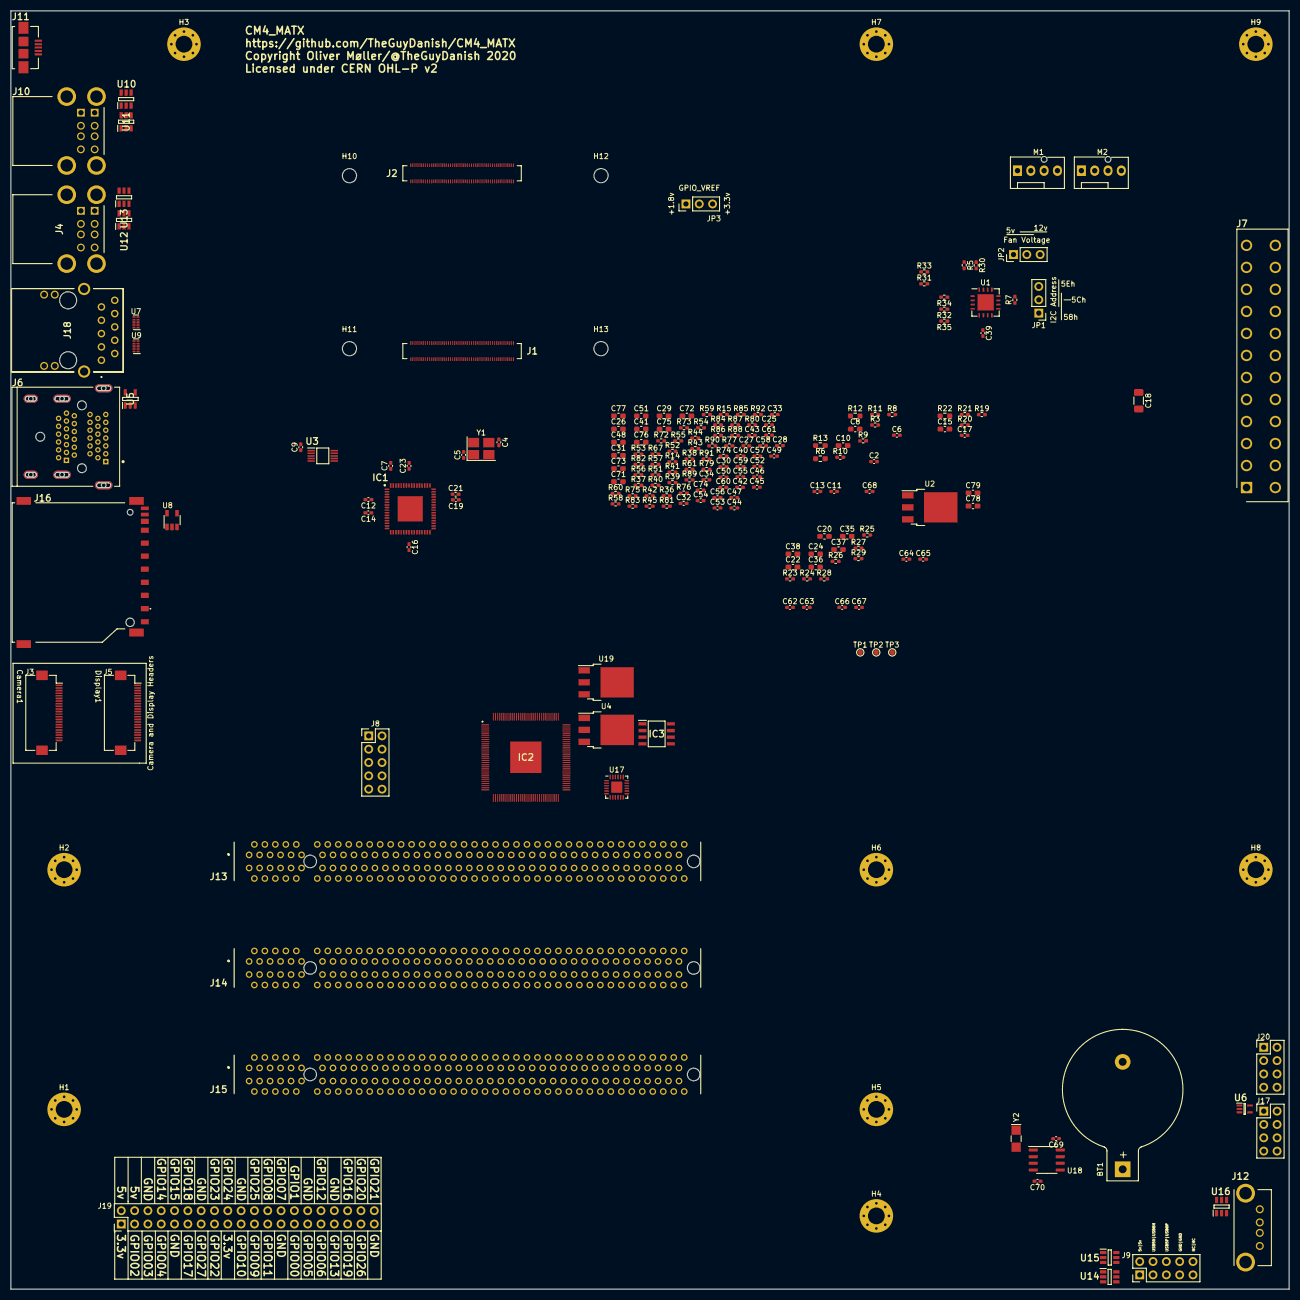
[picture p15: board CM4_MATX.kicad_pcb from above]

Board: 4 copper layers, 243.8 x 243.8 mm, 214 parts (0 on the bottom side), 283 nets, no tracks yet.

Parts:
BT1: Battery_Cell; BatteryHolder_Keystone_103_1x20mm
C2, C6, C7, C9, C11, C12, C13, C14, C16, C17, C19, C21, C23, C25, C27, C28, C30, C32, C33, C34, C39, C40, C42, C43, C44, C45, C46, C47, C49, C50, C52, C53, C54, C55, C56, C57, C58, C59, C60, C61, C62, C63, C64, C65, C66, C67, C68, C69, C70, C74: 100nF; C_0402_1005Metric_Pad0.74x0.62mm_HandSolder
C4, C5: 16pF; C_0402_1005Metric_Pad0.74x0.62mm_HandSolder
C8, C10, C15, C20, C22, C24, C26, C29, C31, C35, C36, C37, C38, C41, C48, C51, C71, C72, C73, C75, C76, C77, C78, C79: 10uF; C_0603_1608Metric_Pad1.08x0.95mm_HandSolder
C18: 100uF; C_1206_3216Metric_Pad1.33x1.80mm_HandSolder
H1, H2, H3, H4, H5, H6, H7, H8, H9: MountingHole; MountingHole_3.2mm_M3_Pad_Via
H10, H11, H12, H13: MountingHole; MountingHole_2.7mm_M2.5
IC1: USB2517-JZX; QFN50P900X900X100-65N-D
IC2: PI7C9X2G404SLBFDE; QFP40P1600X1600X160-129N
IC3: M24C04-RMN6TP; SOIC127P600X175-8N
J1: CM4_B; DF40C100DS04V51_B
J2: CM4_A; DF40C100DS04V51
J3, J5: Conn_01x22_Female; Hirose_FH12-22S-0.5SH_1x22-1MP_P0.50mm_Horizontal
J4, J10: 72309-8014BLF; 723098014BLF
J6: 1888811-1; TE_1888811-1
J7: 39-28-1243; SHDR24W125P550X420_2X12_5160X960X1310P
J8, J9: Conn_02x05_Odd_Even; PinHeader_2x05_P2.54mm_Vertical
J11: 10104110-0001LF; 101041100001LF
J12: SS-52100-002; SS52100002
J13, J14, J15: PCIe_x16; 10018783-10113TLF
J16: GSD090012SEU
J17, J20: Conn_02x04_Odd_Even; PinHeader_2x04_P2.54mm_Vertical
J18: ARJM11C7-502-AB-ER2-T; ARJM11C7502ABER2T
J19: Conn_02x20_Odd_Even; PinHeader_2x20_P2.54mm_Vertical
JP1, JP2, JP3: Jumper_3_Open; PinHeader_1x03_P2.54mm_Vertical
M1, M2: Fan_CPU_4pin; FanPinHeader_1x04_P2.54mm_Vertical
R3, R8, R9, R10, R11: 100K 5%; R_0402_1005Metric_Pad0.72x0.64mm_HandSolder
R5, R7, R30, R31, R32, R33, R34, R35: 4.7K; R_0402_1005Metric_Pad0.72x0.64mm_HandSolder
R6, R22: 12K 1%; R_0603_1608Metric_Pad0.98x0.95mm_HandSolder
R12, R13: 2.2K 1%; R_0603_1608Metric_Pad0.98x0.95mm_HandSolder
R14: 475 1%; R_0402_1005Metric_Pad0.72x0.64mm_HandSolder
R15: 1.43k 1%; R_0402_1005Metric_Pad0.72x0.64mm_HandSolder
R19: 1K 1%; R_0402_1005Metric_Pad0.72x0.64mm_HandSolder
R20, R21: 470 1%; R_0402_1005Metric_Pad0.72x0.64mm_HandSolder
R23, R24, R25, R26, R27, R28, R29: 143 1%; R_0402_1005Metric_Pad0.72x0.64mm_HandSolder
R36, R37, R38, R39, R40, R73, R74, R75, R76, R77, R79, R80, R81, R82: 330; R_0402_1005Metric_Pad0.72x0.64mm_HandSolder
R41, R42, R43, R44, R45, R51, R52, R53, R67, R72, R91, R92: 5.1k; R_0402_1005Metric_Pad0.72x0.64mm_HandSolder
R54, R55, R56, R57, R58, R59, R60, R61: 33; R_0402_1005Metric_Pad0.72x0.64mm_HandSolder
R83, R84, R85, R86, R87, R88, R89, R90: 49.9; R_0402_1005Metric_Pad0.72x0.64mm_HandSolder
TP1: STATUS2; TestPoint_Pad_D1.0mm
TP2: STATUS0; TestPoint_Pad_D1.0mm
TP3: STATUS1; TestPoint_Pad_D1.0mm
U1: MAX6639ATE+; TQFN-16-1EP_5x5mm_P0.8mm_EP3.1x3.1mm
U2: AP7363-33D; TO-252-3_TabPin2
U3: FSUSB42MUX; SOP50P490X110-10N
U4, U19: AP7363-10D; TO-252-3_TabPin2
U5: AP2822CKETR-G1; SOT95P282X145-5N
U6: 74LVC1G07GW; SOT65P212X110-5N
U7, U9: TPD4EUSB30; USON-10_2.5x1.0mm_P0.5mm
U8: RT9742GGJ5; TSOT-23-5
U10, U11, U12, U13, U14, U15, U16: MIC2019YM6-TR; SOT95P280X145-6N
U17: TCA9548ARGER; Texas_RGE0024C_EP2.1x2.1mm
U18: PCF85263AT; SO-8_3.9x4.9mm_P1.27mm
Y1: 24MHz; Crystal_SMD_3225-4Pin_3.2x2.5mm_HandSoldering
Y2: 32.768KHz; Crystal_SMD_MicroCrystal_CC7V-T1A-2Pin_3.2x1.5mm_HandSolder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

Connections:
+3.3VA: C51.1, C57.1, C76.1, C79.1, IC2.15, J13.B10, J14.B10, J15.B10, U2.3, U19.1
+3.3VP: C68.1, J8.1, J13.A9, J13.A10, J13.B8, J14.A9, J14.A10, J14.B8, J15.A9, J15.A10, J15.B8, U17.21
+3V3: C7.1, C8.1, C9.1, C10.1, C12.1, C14.1, C16.1, C19.1, C21.1, C23.1, C26.1, C29.1, C32.1, C39.1, C40.1, C41.1, C44.1, C45.1, C48.1, C49.1, C50.1, C55.1, C56.1, C58.1, C72.1, C74.1, IC1.5, IC1.10, IC1.24, IC1.52, IC1.57, IC1.64, IC2.1, IC2.8, IC2.49, IC2.64, IC2.79, IC2.82, IC2.84, IC2.96, IC2.113, IC3.8, J3.22, J5.22, J7.2, J7.12, J7.13, JP1.3, R7.2, R32.2, R34.2, R35.2, R41.2, R42.2, R43.2, R44.2, R45.2, R51.1, R52.1, R53.1, R67.2, R72.2, R91.1, R92.1, U1.6, U3.1, U4.1
+12P: J13.A2, J13.A3, J13.B1, J13.B2, J13.B3, J14.A2, J14.A3, J14.B1, J14.B2, J14.B3, J15.A2, J15.A3, J15.B1, J15.B2, J15.B3
+12V: J7.10, J7.11, JP2.3
/+5v: C11.1, C18.1, C20.1, C22.1, C24.1, C35.1, C36.1, C37.1, C38.1, C69.1, J2.77, J7.4, J7.6, J7.21, J7.22, J7.23, J19.2, J19.4, JP2.1, U5.4, U5.5, U10.1, U11.1, U12.1, U13.1, U14.1, U15.1, U16.1, U18.8
/+5vSB: C78.1, J7.9, U2.1
/CAM_GPIO: J2.97, J3.17
/CM4_GPIO/+1.8v: J2.88, J2.90, JP3.1
/CM4_GPIO/+3.3v: J2.84, J2.86, J18.L1, J18.L3, J19.1, J19.17, JP3.3, R22.1, U6.5, U8.5
/CM4_GPIO/BT_nDis: J2.91, J20.3
/CM4_GPIO/EEPROM_nWP: J2.20, J20.7
/CM4_GPIO/ETH_LEDG: J2.15, R20.1
/CM4_GPIO/ETH_LEDY: J2.17, R21.1
/CM4_GPIO/FP_PLED: R19.1, U6.4
/CM4_GPIO/GPIO2: J2.58, J19.3
/CM4_GPIO/GPIO3: J2.56, J19.5
/CM4_GPIO/GPIO4: J2.54, J19.7
/CM4_GPIO/GPIO5: J2.34, J19.29
/CM4_GPIO/GPIO6: J2.30, J19.31
/CM4_GPIO/GPIO7: J2.37, J19.26
/CM4_GPIO/GPIO8: J2.39, J19.24
/CM4_GPIO/GPIO9: J2.40, J19.21
/CM4_GPIO/GPIO10: J2.44, J19.19
/CM4_GPIO/GPIO11: J2.38, J19.23
/CM4_GPIO/GPIO12: J2.31, J19.32
/CM4_GPIO/GPIO13: J2.28, J19.33
/CM4_GPIO/GPIO14: J2.55, J19.8
/CM4_GPIO/GPIO15: J2.51, J19.10
/CM4_GPIO/GPIO16: J2.29, J19.36
/CM4_GPIO/GPIO17: J2.50, J19.11
/CM4_GPIO/GPIO18: J2.49, J19.12
/CM4_GPIO/GPIO19: J2.26, J19.35
/CM4_GPIO/GPIO20: J2.27, J19.38
/CM4_GPIO/GPIO21: J2.25, J19.40
/CM4_GPIO/GPIO22: J2.46, J19.15
/CM4_GPIO/GPIO23: J2.47, J19.16
/CM4_GPIO/GPIO24: J2.45, J19.18
/CM4_GPIO/GPIO25: J2.41, J19.22
/CM4_GPIO/GPIO26: J2.24, J19.37
/CM4_GPIO/GPIO27: J2.48, J19.13
/CM4_GPIO/PI_nLED_ACT: J2.21, J17.3
/CM4_GPIO/RUN_PG: J2.92, J17.7
/CM4_GPIO/SD_CLK: J2.57, J16.5
/CM4_GPIO/SD_CMD: J2.62, J16.2
/CM4_GPIO/SD_DAT0: J2.63, J16.7
/CM4_GPIO/SD_DAT1: J2.67, J16.8
/CM4_GPIO/SD_DAT2: J2.69, J16.9
/CM4_GPIO/SD_DAT3: J2.61, J16.1
/CM4_GPIO/SD_DET: J2.76, J16.10
/CM4_GPIO/SD_PWR: C15.1, J16.4, U8.1
/CM4_GPIO/SD_PWR_ON: J2.75, R22.2, U8.4
/CM4_GPIO/TRD0_N: J2.10, J18.2, U7.4
/CM4_GPIO/TRD0_P: J2.12, J18.1, U7.5
/CM4_GPIO/TRD1_N: J2.6, J18.4, U7.2
/CM4_GPIO/TRD1_P: J2.4, J18.3, U7.1
/CM4_GPIO/TRD2_N: J2.9, J18.8, U9.4
/CM4_GPIO/TRD2_P: J2.11, J18.7, U9.5
/CM4_GPIO/TRD3_N: J2.5, J18.10, U9.2
/CM4_GPIO/TRD3_P: J2.3, J18.9, U9.1
/CM4_GPIO/WL_nDis: J2.89, J20.1
/CM4_GPIO/nPWR_LED: J2.95, U6.2
/CM4_GPIO/nRPIBOOT: J2.93, J20.5
/CM4_HighSpeed/CAM1_C_N: J1.127, J3.8
/CM4_HighSpeed/CAM1_C_P: J1.129, J3.9
/CM4_HighSpeed/CAM1_D0_N: J1.115, J3.2
/CM4_HighSpeed/CAM1_D0_P: J1.117, J3.3
/CM4_HighSpeed/CAM1_D1_N: J1.121, J3.5
/CM4_HighSpeed/CAM1_D1_P: J1.123, J3.6
/CM4_HighSpeed/CAM1_D2_N: J1.133, J3.11
/CM4_HighSpeed/CAM1_D2_P: J1.135, J3.12
/CM4_HighSpeed/CAM1_D3_N: J1.139, J3.14
/CM4_HighSpeed/CAM1_D3_P: J1.141, J3.15
/CM4_HighSpeed/DSI1_C_N: J1.187, J5.8
/CM4_HighSpeed/DSI1_C_P: J1.189, J5.9
/CM4_HighSpeed/DSI1_D0_N: J1.175, J5.2
/CM4_HighSpeed/DSI1_D0_P: J1.177, J5.3
/CM4_HighSpeed/DSI1_D1_N: J1.181, J5.5
/CM4_HighSpeed/DSI1_D1_P: J1.183, J5.6
/CM4_HighSpeed/DSI1_D2_N: J1.193, J5.11
/CM4_HighSpeed/DSI1_D2_P: J1.195, J5.12
/CM4_HighSpeed/DSI1_D3_N: J1.194, J5.14
/CM4_HighSpeed/DSI1_D3_P: J1.196, J5.15
/CM4_HighSpeed/HDMI0_CEC: J1.151, J6.AP13
/CM4_HighSpeed/HDMI0_CK_N: J1.190, J6.AP12
/CM4_HighSpeed/HDMI0_CK_P: J1.188, J6.AP10
/CM4_HighSpeed/HDMI0_D0_N: J1.184, J6.AP9
/CM4_HighSpeed/HDMI0_D0_P: J1.182, J6.AP7
/CM4_HighSpeed/HDMI0_D1_N: J1.178, J6.AP6
/CM4_HighSpeed/HDMI0_D1_P: J1.176, J6.AP4
/CM4_HighSpeed/HDMI0_D2_N: J1.172, J6.AP3
/CM4_HighSpeed/HDMI0_D2_P: J1.170, J6.AP1
/CM4_HighSpeed/HDMI0_HOTPLUG: J1.153, J6.AP19
/CM4_HighSpeed/HDMI0_SCL: J1.200, J6.AP15
/CM4_HighSpeed/HDMI0_SDA: J1.199, J6.AP16
/CM4_HighSpeed/HDMI1_CEC: J1.149, J6.BP13
/CM4_HighSpeed/HDMI1_CK_N: J1.166, J6.BP12
/CM4_HighSpeed/HDMI1_CK_P: J1.164, J6.BP10
/CM4_HighSpeed/HDMI1_D0_N: J1.160, J6.BP9
/CM4_HighSpeed/HDMI1_D0_P: J1.158, J6.BP7
/CM4_HighSpeed/HDMI1_D1_N: J1.154, J6.BP6
/CM4_HighSpeed/HDMI1_D1_P: J1.152, J6.BP4
/CM4_HighSpeed/HDMI1_D2_N: J1.148, J6.BP3
/CM4_HighSpeed/HDMI1_D2_P: J1.146, J6.BP1
/CM4_HighSpeed/HDMI1_HOTPLUG: J1.143, J6.BP19
/CM4_HighSpeed/HDMI1_SCL: J1.147, J6.BP15
/CM4_HighSpeed/HDMI1_SDA: J1.145, J6.BP16
/CM4_HighSpeed/HDMI_5v: C13.1, J6.AP18, J6.BP18, U5.1
/CM4_HighSpeed/PCIE_CLK_N: IC2.73, J1.112
/CM4_HighSpeed/PCIE_CLK_P: IC2.74, J1.110
/CM4_HighSpeed/PCIE_NRST: IC2.10, J1.109
/CM4_HighSpeed/PCIE_RX_N: IC2.123, J1.118
/CM4_HighSpeed/PCIE_RX_P: IC2.124, J1.116
/CM4_HighSpeed/USB2_N: J1.103, U3.4
/CM4_HighSpeed/USB2_P: J1.105, U3.3
/CM4_USB2_Power/HD1_5v: J10.A1, U10.6
/CM4_USB2_Power/HD2_5v: J10.B1, U11.6
/CM4_USB2_Power/HD3_5v: J4.A1, U12.6
/CM4_USB2_Power/HD4_5v: J4.B1, U13.6
/CM4_USB2_Power/HD5_5v: J9.1, U14.6
/CM4_USB2_Power/HD6_5v: J9.2, U15.6
/CM4_USB2_Power/HD7_5v: J12.1, U16.6
/CM4_USB2_Power/USB1_PWR: IC1.29, U10.3
/CM4_USB2_Power/USB2_PWR: IC1.26, U11.3
/CM4_USB2_Power/USB3_PWR: IC1.23, U12.3
/CM4_USB2_Power/USB4_PWR: IC1.20, U13.3
/CM4_USB2_Power/USB5_PWR: IC1.30, U14.3
/CM4_USB2_Power/USB6_PWR: IC1.39, U15.3
/CM4_USB2_Power/USB7_PWR: IC1.36, U16.3
/CM4_USB2_Power/nOCS1: IC1.28, U10.4
/CM4_USB2_Power/nOCS2: IC1.27, U11.4
/CM4_USB2_Power/nOCS3: IC1.22, U12.4
/CM4_USB2_Power/nOCS4: IC1.21, U13.4
/CM4_USB2_Power/nOCS5: IC1.35, U14.4
/CM4_USB2_Power/nOCS6: IC1.38, U15.4
/CM4_USB2_Power/nOCS7: IC1.37, U16.4
/FanCTRL_MAX6639/ADD: JP1.2, U1.11
/FanCTRL_MAX6639/DX: U1.8, U1.9, U1.10
/FanCTRL_MAX6639/PWM1: M1.4, R30.2, U1.15
/FanCTRL_MAX6639/PWM2: M2.4, R33.2, U1.1
/FanCTRL_MAX6639/TACH1: M1.3, R5.2, U1.16
/FanCTRL_MAX6639/TACH2: M2.3, R31.2, U1.2
/FanCTRL_MAX6639/V_FAN: JP2.2, M1.2, M2.2, R5.1, R30.1, R31.1, R33.1
/FanCTRL_MAX6639/~ALERT: R7.1, U1.12
/FanCTRL_MAX6639/~FANFAIL: R34.1, U1.3
/FanCTRL_MAX6639/~OT: R35.1, U1.5
/FanCTRL_MAX6639/~THERM: R32.1, U1.4
/GPIO_VREF: J2.78, JP3.2
/ID_SC: J2.35, J19.28
/ID_SD: J2.36, J19.27
/PCIe_Subsystem/PCIE1_SMBUS_CLK: J13.B5, U17.4
/PCIe_Subsystem/PCIE1_SMBUS_DATA: J13.B6, U17.3
/PCIe_Subsystem/PCIE2_SMBUS_CLK: J14.B5, U17.6
/PCIe_Subsystem/PCIE2_SMBUS_DATA: J14.B6, U17.5
/PCIe_Subsystem/PCIE3_SMBUS_CLK: J15.B5, U17.8
/PCIe_Subsystem/PCIE3_SMBUS_DATA: J15.B6, U17.7
/PCIe_Subsystem/PCIESW_SMBUS_CLK: IC2.26, U17.2
/PCIe_Subsystem/PCIESW_SMBUS_DATA: IC2.27, U17.1
/PCIe_Subsystem/PCIE_RX_N: IC2.127, J1.124
/PCIe_Subsystem/PCIE_RX_P: IC2.128, J1.122
/PCIe_Subsystem/PCIE_SW_TCK: IC2.89, J8.4
/PCIe_Subsystem/PCIE_SW_TMS: IC2.92, J8.2
/PCIe_Subsystem/PCIe_Slot1/PCIE1_CLK_N: J13.A14, R57.1, R86.2
/PCIe_Subsystem/PCIe_Slot1/PCIE1_CLK_P: J13.A13, R56.1, R85.2
/PCIe_Subsystem/PCIe_Slot1/PCIE1_PERST: IC2.5, J13.A11, R51.2
/PCIe_Subsystem/PCIe_Slot1/PCIE1_PRSNT: IC2.19, J13.B17
/PCIe_Subsystem/PCIe_Slot1/PCIE1_RX_N: IC2.101, J13.A16
/PCIe_Subsystem/PCIe_Slot1/PCIE1_RX_P: IC2.100, J13.A17
/PCIe_Subsystem/PCIe_Slot1/PCIe_1_TX_N: C65.1, J13.B15
/PCIe_Subsystem/PCIe_Slot1/PCIe_1_TX_P: C64.2, J13.B14
/PCIe_Subsystem/PCIe_Slot2/PCIE2_CLK_N: C62.1, IC2.102, J14.A14, R59.1, R88.2
/PCIe_Subsystem/PCIe_Slot2/PCIE2_CLK_P: J14.A13, R58.1, R87.2
/PCIe_Subsystem/PCIe_Slot2/PCIE2_PERST: IC2.6, J14.A11, R52.2
/PCIe_Subsystem/PCIe_Slot2/PCIE2_PRSNT: IC2.20, J14.B17
/PCIe_Subsystem/PCIe_Slot2/PCIE2_RX_N: IC2.107, J14.A17
/PCIe_Subsystem/PCIe_Slot2/PCIE2_RX_P: IC2.106, J14.A16
/PCIe_Subsystem/PCIe_Slot2/PCIe_2_TX_N: C63.1, J14.B15
/PCIe_Subsystem/PCIe_Slot2/PCIe_2_TX_P: C62.2, J14.B14
/PCIe_Subsystem/PCIe_Slot3/PCIE3_CLK_N: J15.A14, R61.1, R90.2
/PCIe_Subsystem/PCIe_Slot3/PCIE3_CLK_P: J15.A13, R60.1, R89.2
/PCIe_Subsystem/PCIe_Slot3/PCIE3_PERST: IC2.7, J15.A11, R53.2
/PCIe_Subsystem/PCIe_Slot3/PCIE3_PRSNT: IC2.21, J15.B17
/PCIe_Subsystem/PCIe_Slot3/PCIE3_RX_N: IC2.117, J15.A17
/PCIe_Subsystem/PCIe_Slot3/PCIE3_RX_P: IC2.118, J15.A16
/PCIe_Subsystem/PCIe_Slot3/PCIe_3_TX_N: C67.1, J15.B15
/PCIe_Subsystem/PCIe_Slot3/PCIe_3_TX_P: C66.2, J15.B14
/PCIe_Subsystem/PCIe_Switch/+1.0v: C25.1, C27.1, C28.1, C30.1, C31.1, C33.1, C34.1, C42.1, C43.1, C46.1, C47.1, C52.1, C53.1, C59.1, C60.1, C71.1, C75.1, IC2.3, IC2.23, IC2.29, IC2.31, IC2.40, IC2.55, IC2.62, IC2.65, IC2.91, IC2.99, IC2.105, IC2.108, IC2.119, IC2.125, U4.3
/PCIe_Subsystem/PCIe_Switch/+1.0vSB: C54.1, C61.1, C73.1, C77.1, IC2.13, IC2.14, U19.3
/PCIe_Subsystem/PCIe_Switch/CGND: IC2.109, IC2.112
/PCIe_Subsystem/PCIe_Switch/CLKBUF_PD: IC2.60, R82.2
/PCIe_Subsystem/PCIe_Switch/CLKQ0_N: R55.1, R84.2
/PCIe_Subsystem/PCIe_Switch/CLKQ0_P: R54.1, R83.2
/PCIe_Subsystem/PCIe_Switch/EECLK: IC2.70, IC3.6, R91.2
/PCIe_Subsystem/PCIe_Switch/EEPD: IC2.71, IC3.5, R92.2
/PCIe_Subsystem/PCIe_Switch/GPIO0: IC2.36, R36.2
/PCIe_Subsystem/PCIe_Switch/GPIO1: IC2.35, R37.2
/PCIe_Subsystem/PCIe_Switch/GPIO2: IC2.37, R38.2
/PCIe_Subsystem/PCIe_Switch/GPIO3: IC2.38, R39.2
/PCIe_Subsystem/PCIe_Switch/GPIO4: IC2.39, R40.2
/PCIe_Subsystem/PCIe_Switch/IREF: IC2.86, R14.2
/PCIe_Subsystem/PCIe_Switch/PCIE1_RX_N: C65.2, IC2.98
/PCIe_Subsystem/PCIe_Switch/PCIE1_RX_P: C64.1, IC2.97
/PCIe_Subsystem/PCIe_Switch/PCIE2_RX_N: C63.2, IC2.103
/PCIe_Subsystem/PCIe_Switch/PCIE3_RX_N: C67.2, IC2.121
/PCIe_Subsystem/PCIe_Switch/PCIE3_RX_P: C66.1, IC2.122
/PCIe_Subsystem/PCIe_Switch/PL_512B: IC2.53, R81.2
/PCIe_Subsystem/PCIe_Switch/PWR_SAV: IC2.28, R67.1
/PCIe_Subsystem/PCIe_Switch/REXT: IC2.116, R15.2
/PCIe_Subsystem/PCIe_Switch/REXT_GND: IC2.115, R15.1
/PCIe_Subsystem/PCIe_Switch/RXPOLINV_DIS: IC2.24, R76.2
/PCIe_Subsystem/PCIe_Switch/SCAN_EN: IC2.72, R79.2
/PCIe_Subsystem/PCIe_Switch/SLOTCLK: IC2.33, R41.1
/PCIe_Subsystem/PCIe_Switch/SLOT_IMP1: IC2.45, R42.1
/PCIe_Subsystem/PCIe_Switch/SLOT_IMP2: IC2.46, R43.1
/PCIe_Subsystem/PCIe_Switch/SLOT_IMP3: IC2.47, R44.1
/PCIe_Subsystem/PCIe_Switch/TEST1: IC2.9, R45.1
/PCIe_Subsystem/PCIe_Switch/TEST2: IC2.16, R72.1
/PCIe_Subsystem/PCIe_Switch/TEST3: IC2.17, R73.2
/PCIe_Subsystem/PCIe_Switch/TEST4: IC2.22, R75.2
/PCIe_Subsystem/PCIe_Switch/TEST5: IC2.25, R77.2
/PCIe_Subsystem/PCIe_Switch/TEST6: IC2.51, R80.2
/PCIe_Subsystem/PCIe_Switch/VC1_EN: IC2.18, R74.2
/RTC_PCF85263A/OSCI: U18.1, Y2.1
/RTC_PCF85263A/OSCO: U18.2, Y2.2
/RTC_PCF85263A/VBAT: BT1.1, C70.1, U18.3
/SCL0: J2.80, J3.20, J5.20, U1.13, U17.19, U18.6
/SDA0: J2.82, J3.21, J5.21, U1.14, U17.20, U18.5
/USB2_HUB/3.3v: IC1.44, IC1.46
/USB2_HUB/HD1_N: IC1.1, J10.A2
/USB2_HUB/HD1_P: IC1.2, J10.A3
/USB2_HUB/HD2_N: IC1.3, J10.B2
/USB2_HUB/HD2_P: IC1.4, J10.B3
/USB2_HUB/HD3_N: IC1.6, J4.A2
/USB2_HUB/HD3_P: IC1.7, J4.A3
/USB2_HUB/HD4_N: IC1.8, J4.B2
/USB2_HUB/HD4_P: IC1.9, J4.B3
/USB2_HUB/HD5_N: IC1.11, J9.3
/USB2_HUB/HD5_P: IC1.12, J9.5
/USB2_HUB/HD6_N: IC1.53, J9.4
/USB2_HUB/HD6_P: IC1.54, J9.6
/USB2_HUB/HD7_N: IC1.55, J12.2
/USB2_HUB/HD7_P: IC1.56, J12.3
/USB2_HUB/USBH_N: IC1.58, U3.8
/USB2_HUB/USBH_P: IC1.59, U3.9
/USB2_HUB/USBOTG: J1.101, R12.1, R13.2, U3.2
/USB2_HUB/XTAL1: C4.2, IC1.61, Y1.3
/USB2_HUB/XTAL2: C5.1, IC1.60, Y1.1
/nEXTRST: IC1.43, J2.100
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

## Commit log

2020-11-14 Big changes (see expanded comment)
    Added new components:
    USB2517-JZX USB2.0 Hub
    SI-52100-002 Vertical USB2.0 A Header
    Began work on USB schematic, mostly done. Needs power delivery work done
    [ATX_PSU.kicad_sch, CM4_HighSpeed.kicad_sch, CM4_MATX.kicad_pcb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]
2020-11-15 placed mounting holes as per specification
    (0,0) on top left
    [CM4_MATX.kicad_pcb]
2020-11-15 Preliminary component placement and PCB PDF
    [CM4_MATX.kicad_pcb]
2020-11-19 Where do I even start...
    Rebasing the entire project to use KiCad 5.1.8 stable instead of nightly.
    Most of the progress made on the schematic still in place, with a few exceptions that I can handle over the next few days.
    Additonally. Resolves #17, #19, and parts of #18 (I still want to build some automated checks into the project once we are at a more advanced state)
    [ATX_PSU.kicad_sch, CM4_ATX_PSU.sch, CM4_HighSpeed.kicad_sch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]
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2020-11-19 added mounting holes to CM4_MATX.sch
    [CM4_MATX.sch]
2020-11-19 added pcb dimensions and mounting holes
    [CM4_MATX.kicad_pcb]
2020-11-19 fixed missplaced mountinghole H3
    [CM4_MATX.kicad_pcb]
2020-11-19 added rear io window placeholder
    [CM4_MATX.kicad_pcb]
2020-11-19 changed page size to A3
    [CM4_MATX.kicad_pcb]
2020-11-21 Lotsa changes
    Added new footprints:
    PCIe x1, TO-252 tab, SOT95, SOP50, SON50, Hirose FH-12-22S, 2.54mm 2x02 and 2x05 headers
    Added new models:
    Hirose FH-12-22S, FSUSB42MUX, MIC2019YM6-TR, TPS6206
    Re-did ATX connector symbol wiring
    Begun wiring PI7C PCI-e switch
    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
    [CM4_ATX_PSU.sch, CM4_HighSpeed.sch, CM4_MATX.kicad_pcb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]
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2020-11-22 Clean up references to _LibLoader library
    [CM4_MATX.kicad_pcb]
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2020-11-23 Add 3D rendering of PCB. 3D rendering created by exporting from KiCad to VRML format, and importing it in Blender 2.79 (later versions ignore color on VRML import) NOTE: KiCad->VRML->Blender export/i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
    See issue TheGuyDanish/CM4_MATX#14
2020-11-24 Many, many changes...
    Added a bunch of new footprints and a couple of new symbols.
    Added the other side of the CM4 connector and wired its features.
    Added some more detailed models for a fair few components.
    Added a new schematic to handle power for USB ports.
    Updated the PCB with the new components and moved some around to populate the rear IO panel.
    [CM4_ATX_PSU.sch, CM4_GPIO.sch, CM4_HighSpeed.sch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]
2020-11-25 Added a new 3.3V-1.0V regulator
    (I was intending for this to be part of a bigger commit where I finally fix the PI7C power delivery, but it proved a little too daunting for the moment.)
2020-11-27 Small changes to PCIe, USB Schematics and board layout, legend for GPIO pins.
    [CM4_ATX_PSU.sch, CM4_GPIO.sch, CM4_HighSpeed.sch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]
2020-12-14 Added License text, fixes #30, updated PCB to include copyright notice.
    [CM4_ATX_PSU.sch, CM4_GPIO.sch, CM4_HighSpeed.sch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]
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2020-12-18 fixed mounting holes
    [CM4_MATX.kicad_pcb]
2020-12-19 Updating PCIe symbols + PCIe power stub sheet
    [CM4_ATX_PSU.sch, CM4_GPIO.sch, CM4_HighSpeed.sch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]
2020-12-20 Updated schematic PDF and re-did PSU-PCIe_PWR connections
    [CM4_MATX.sch]
2020-12-20 updated dimensions
    begin of dimensional chain for the board is the bottom left corner at X1.5 Y10.5
    [CM4_MATX.kicad_pcb]
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2020-12-20 Moved J13-15 to fix overlap
    [CM4_MATX.kicad_pcb]
2020-12-22 Updated PCI-e switch with more power wiring
    Still needs more work on connectivity before #28 can be solved.
    [CM4_PCIe_Switch.sch]
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2020-12-23 added schematic of FanCTRL with MAX6639
    [CM4_FanCTRL_MAX6639.sch, CM4_MATX.sch]
2020-12-23 placed footprints on pcb as a functional group
    [CM4_MATX.kicad_pcb]
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2020-12-23 updated printouts of schematics and pcb
    [CM4_FanCTRL_MAX6639.sch, CM4_MATX.kicad_pcb, CM4_MATX.sch]
2020-12-23 updated sheet numeration of schematic files
    [CM4_ATX_PSU.sch, CM4_GPIO.sch, CM4_HighSpeed.sch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]
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2020-12-24 changed file name to *.stp
    to match the other files
    [CM4_MATX.kicad_pcb]
2020-12-24 Replaced Ethernet connector and removed unnecessary files
    Fixes #38
    [CM4_GPIO.sch, CM4_MATX.kicad_pcb]
2020-12-24 Corrected library the ARJM11C7 schematic is loaded from
    [CM4_GPIO.sch]
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2020-12-25 moved pcie connectors to location
    as per https://www.silverstonetek.com/techtalk/11008/pic-7.png
    [CM4_MATX.kicad_pcb]
2020-12-25 locked mounting holes and pcie connectors
    as they are dependent on each others position
    [CM4_MATX.kicad_pcb]
2020-12-25 renumbered erroring net
    [CM4_MATX.kicad_pcb]
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2020-12-27 fixed 3D settings of PCIe footprints
    [CM4_MATX.kicad_pcb]
2020-12-28 Added 3.3v standby voltage regulator for PCI-e auxiliary power
    [CM4_ATX_PSU.sch, CM4_MATX.sch, CM4_PCIe_Switch.sch]
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2020-12-30 Adding PCIe subsystem
    - Moves a lot of the PCIe related items from the top level sheet to a new sheet called PCIe Subsystem which then has other hierarchical sheets below it.
    - This adds some of the AC coupling caps for the PCIe slots, might need to do some work with the switch yet.
    - Adds an SMBUS mux for the SMBUS connections to the PCIe slots. Extra SMBUS lanes sit un-wired and can be used for other things.
    - Adds JTAG headers for the PCIe connectors.
    [CM4_ATX_PSU.sch, CM4_FanCTRL_MAX6639.sch, CM4_GPIO.sch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]
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2021-01-03 fixed 3D model offset of PCIe slots
    [CM4_MATX.kicad_pcb]
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2021-01-07 Removing Display0 and Camera0
    Eliminates the need for J1, R1 and R2. Also removed.
    [CM4_HighSpeed.sch]
2021-01-07 Tons of wiring and pin straps for PCI-e Switch
    Also re-did some hierarchical labels for JTAG
    [CM4_GPIO.sch, CM4_MATX.sch, CM4_PCIe_JTAG_Connectors.sch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]
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2021-01-07 Added second USB dual-stack header and fixed some library references.
    [CM4_MATX.kicad_pcb, CM4_PCIe_JTAG_Connectors.sch, CM4_PCIe_Port_1.sch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]
2021-01-10 fixed pin1 marker on ARJM connector
    it broke the wrl export for later rendering
    [CM4_MATX.kicad_pcb]
2021-01-18 PCIe Wiring, resistor value adjustments, and a bunch of small ERC fixes.
    [CM4_FanCTRL_MAX6639.sch, CM4_GPIO.sch, CM4_HighSpeed.sch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]
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2021-02-08 Updated CM4 footprints/symbols, mounting holes
    This is in a bid to make it more manufactuerable by reducing the need for explanations and questions.
    [CM4_ATX_PSU.sch, CM4_FanCTRL_MAX6639.sch, CM4_GPIO.sch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]
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2021-03-01 Started picking passive components, overhauled library
    Cleaned up a bunch of schematic library references.
    Added datasheets, descriptions for a lot of existing parts.
    Picked most capacitor parts, still a couple left.
    Cleaned up a fair few footprint references.
    [CM4_ATX_PSU.sch, CM4_FanCTRL_MAX6639.sch, CM4_GPIO.sch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]
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2021-03-03 Moved C4 and C5 in the schematic to be more logical
    [CM4_USB2_HUB.sch]
2021-03-03 More BOM detailing and small changes
    Removed some NC components from the PCI-e subsection
    Picked resistor footprints
    Picked resistor items in the BOM
    [CM4_USB2_HUB.sch, CM4_USB2_Power.sch]
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2021-03-03 Imported new components to the PCB and moved some components
    Updated PDFs and added two new board layers. One for ground and a second for power (voltage to be decided)
    [CM4_ATX_PSU.sch, CM4_FanCTRL_MAX6639.sch, CM4_GPIO.sch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]
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2021-05-28 More CI fixing/testing
    [CM4_MATX.sch]
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

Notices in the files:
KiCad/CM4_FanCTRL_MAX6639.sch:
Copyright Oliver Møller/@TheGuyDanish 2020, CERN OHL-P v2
